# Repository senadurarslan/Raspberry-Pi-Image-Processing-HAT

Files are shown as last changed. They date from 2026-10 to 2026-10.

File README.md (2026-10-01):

# Raspberry Pi Image Processing HAT

A custom **Raspberry Pi 4 Model B HAT** designed for image capture, processing, and display using an **ArduCAM OV2640 camera**, **ST7735 TFT display**, and an **LM2596S-3.3 based switching power supply**.

<p align="center">
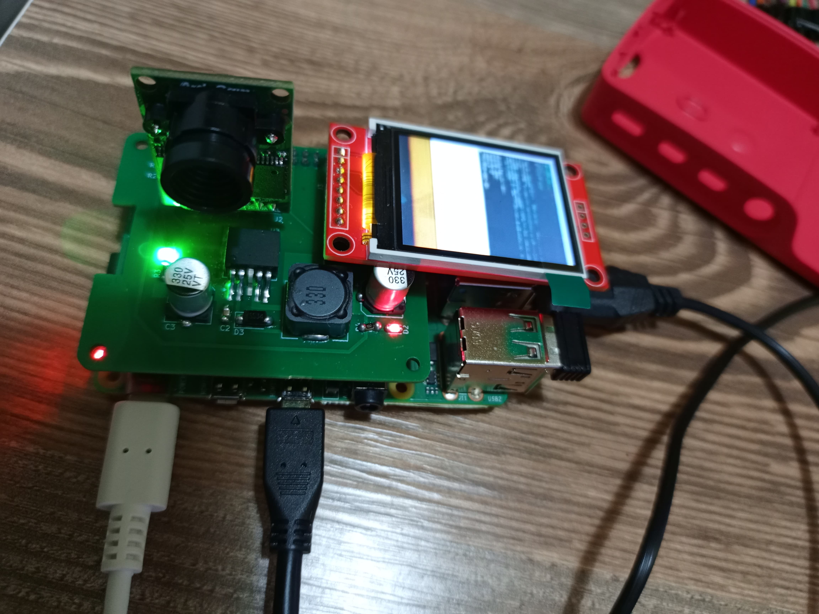
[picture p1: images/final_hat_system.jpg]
Raspberry Pi Image Processing HAT
  
</p>

## Project Overview

This project focuses on the design and implementation of a custom Hardware Attached on Top (**HAT**) board for the Raspberry Pi 4 Model B.

The system captures images using an **ArduCAM OV2640 camera**, processes the image data on the Raspberry Pi, and displays the resulting output on an **ST7735 TFT display**.

A custom PCB was designed to integrate the camera, display, Raspberry Pi GPIO interface, and power management circuitry into a compact embedded vision platform.

The main hardware blocks are:

- **Processing Unit:** Raspberry Pi 4 Model B
- **Image Capture:** ArduCAM Mini OV2640
- **Display:** ST7735 TFT
- **Power Management:** LM2596S-3.3 based SMPS
- **Custom Hardware:** Raspberry Pi HAT PCB

---

## System Architecture

The Raspberry Pi acts as the main processing and control unit.

The **ArduCAM OV2640** communicates with the Raspberry Pi using:

- **I²C** for camera sensor configuration
- **SPI** for image data transfer

The **ST7735 TFT display** uses:

- **SPI** for command and pixel data transfer
- GPIO signals for display control and reset

The overall image processing flow is:

```text
        ArduCAM OV2640
              │
       ┌──────┴──────┐
       │             │
      I²C           SPI
Configuration    Image Data
       │             │
       └──────┬──────┘
              ▼
       Raspberry Pi 4
              │
       JPEG Acquisition
              │
       Buffer Processing
              │
        JPEG Decoding
              │
       RGB565 Conversion
              │
              ▼
       ST7735 TFT Display
```

---

## Hardware Design

The custom HAT PCB was designed using **KiCad EDA**.

The hardware design includes:

- Raspberry Pi 40-pin GPIO interface
- ArduCAM OV2640 camera connector
- ST7735 TFT display connector
- LM2596S-3.3 switching regulator
- SPI communication lines
- I²C communication lines
- Dedicated chip-select signals
- Power distribution circuitry
- Ground plane for improved signal integrity
- SMD and THT components

The PCB was designed as a **two-layer board** and manufactured using the generated Gerber files.

After production, the components were assembled and the board was mounted directly onto the Raspberry Pi for functional testing.

---

## Power Management

An **LM2596S-3.3 based switching power supply (SMPS)** was integrated into the HAT design.

The power stage converts the available supply voltage to the required **3.3 V rail** for the peripheral hardware.

A switching regulator was preferred to provide:

- Higher energy efficiency
- Reduced thermal losses
- Stable output voltage
- Better performance under varying current loads
- Improved suitability for embedded applications

---

## Software Architecture

The software was developed using **C and C++** on Raspberry Pi OS.

The implementation includes:

- ArduChip communication
- OV2640 sensor initialization
- I²C communication
- SPI communication
- JPEG image acquisition
- JPEG file storage
- JPEG decoding
- RGB565 image conversion
- ST7735 TFT display control
- Camera and display integration
- Hardware test programs

### Main Source Files

```text
arduchip.c
arduchip.h

ov2640.c
ov2640.h
ov2640_regs.c
ov2640_regs.h

spi_linux.c
spi_linux.h

i2c_linux.c
i2c_linux.h

jpeg_to_rgb565.c
jpeg_to_rgb565.h

capture_to_file.c
capture_to_screen.cpp
decode_test.c

test_arduchip.c
test_hal.c
```

---

## Build System

The project includes a **Makefile** for compiling and running the camera, image processing, and TFT applications.

### Compilers

The project uses:

```text
gcc
g++
```

The full camera-to-display application is compiled using:

```text
-std=gnu++20
```

### Libraries

The TFT application uses:

```text
rpidisplaygl
lgpio
librt
```

with:

```text
/usr/local/include
/usr/local/lib
```

---

## Build & Run

### Show Available Commands

```bash
make
```

The default target displays the available build and run commands.

### Clean Build Files

```bash
make clean
```

This removes generated object files, executables, and temporary image files such as:

```text
frame.jpg
frame.rgb565
```

---

### ArduChip SPI Test

Compile:

```bash
make test_arduchip
```

Run:

```bash
make run_test_arduchip
```

This test verifies communication with the ArduChip interface.

---

### OV2640 Initialization Test

Compile:

```bash
make test_hal
```

Run:

```bash
make run_test_hal
```

This test verifies OV2640 initialization and communication through the hardware abstraction layer.

---

### Capture JPEG Image

Compile:

```bash
make capture_app
```

Run:

```bash
make run_capture_app
```

The application captures an image from the OV2640 camera and stores the acquired JPEG data.

---

### JPEG to RGB565 Conversion

Compile:

```bash
make decode_test
```

Run:

```bash
make run_decode_test
```

This application tests the conversion of captured JPEG image data into the **RGB565** pixel format used by the TFT display.

---

### Full Camera-to-TFT Pipeline

Compile:

```bash
make capture_screen
```

Run:

```bash
make run_capture_screen
```

This application combines the complete image pipeline:

```text
Camera
  ↓
JPEG Capture
  ↓
Image Processing
  ↓
RGB565 Conversion
  ↓
ST7735 TFT
```

---

# Project Gallery

## Final Integrated HAT System

The final implementation combines the custom HAT PCB, **ArduCAM OV2640 camera**, **ST7735 TFT display**, onboard power stage, and Raspberry Pi into a single integrated system.

<p align="center">
  Final Raspberry Pi HAT System
</p>

---

## Camera Capture Test

The OV2640 camera was configured and tested on the Raspberry Pi.

Image data captured from the camera was transferred to the Raspberry Pi and successfully stored as a JPEG image.

<p align="center">
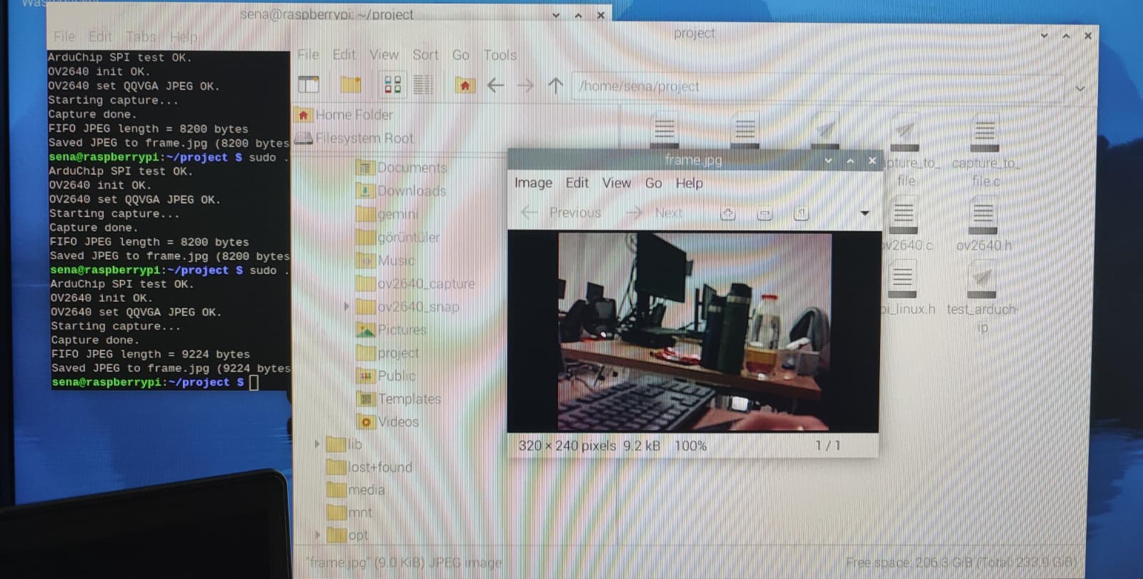
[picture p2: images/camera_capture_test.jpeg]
OV2640 Camera Capture Test
  
</p>

The terminal output verifies the camera communication and image acquisition process, including:

```text
ArduChip SPI test OK
OV2640 init OK
Starting capture...
Capture done
Saved JPEG to frame.jpg
```

---

## Camera-to-TFT Integration Test

The image captured by the OV2640 camera was processed by the Raspberry Pi and displayed on the ST7735 TFT.

<p align="center">
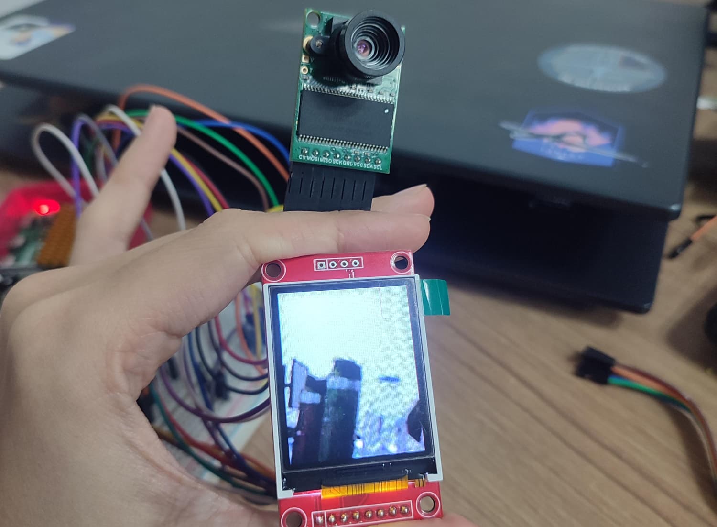
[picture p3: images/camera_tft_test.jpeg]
Camera to TFT Integration Test
  
</p>

This test demonstrates the complete image pipeline from **camera acquisition to TFT visualization**.

---

## Testing

The system was tested incrementally before full integration.

The main test stages included:

- ArduChip SPI communication test
- OV2640 initialization test
- I²C sensor configuration
- SPI image data transfer
- JPEG image capture
- JPEG file storage
- JPEG decoding
- RGB565 conversion
- ST7735 graphical tests
- PCB electrical tests
- Camera and display integration
- Full system functional test

The final system successfully captured image data from the OV2640 camera, processed the image on the Raspberry Pi, and displayed the resulting image on the ST7735 TFT.

---

## PCB Development

The PCB development process consisted of:

```text
System Requirements
        ↓
Component Selection
        ↓
Schematic Design
        ↓
PCB Layout
        ↓
Gerber Generation
        ↓
PCB Manufacturing
        ↓
Component Assembly
        ↓
Electrical Testing
        ↓
Raspberry Pi Integration
        ↓
Functional Testing
```

The PCB design files and manufacturing outputs are included in the repository.

---

## Technologies & Tools

### Hardware

- Raspberry Pi 4 Model B
- ArduCAM OV2640
- ST7735 TFT
- LM2596S-3.3
- Custom Raspberry Pi HAT PCB

### Communication

- SPI
- I²C
- GPIO

### Software

- C
- C++
- GNU Make
- Raspberry Pi OS

### PCB Design

- KiCad EDA
- Gerber
- Two-layer PCB design

---

## Repository Contents

The repository contains:

```text
Raspberry-Pi-Image-Processing-HAT/
│
├── images/
│   ├── final_hat_system.jpg
│   ├── camera_capture_test.jpeg
│   └── camera_tft_test.jpeg
│
├── KiCad/
│   └── PCB and schematic design files
│
├── mühtas_1_project/
│   ├── Camera drivers
│   ├── SPI / I²C drivers
│   ├── Image processing files
│   ├── TFT application
│   └── Makefile
│
├── rapor/
│   └── Project documentation and reports
│
└── README.md
```

---

## Documentation

Detailed project documentation, design reports, system requirements, and test procedures are available in the repository.

The project documentation covers:

- System architecture
- Hardware design
- Power management
- Camera communication
- TFT communication
- PCB design
- Manufacturing
- Software development
- Integration
- Functional testing

---

## Project Context

This project was developed as part of the **MÜHTAS-1 Engineering Design Project** in the **Department of Electronics and Communication Engineering at Kocaeli University**.

The project combines embedded software development, digital communication interfaces, PCB design, power electronics, and image processing into a complete embedded vision system.

---

## Author

**Sena Sümeyye Durarslan**

Electronics and Communication Engineering  
Kocaeli University

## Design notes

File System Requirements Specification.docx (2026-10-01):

System Requirements Specification

AMAÇ: Raspberry Pi’nin 40 pinlik headerı üstüne takılıp çıkarılacak bir HAT tasarlamak.

Sistem, bir kamera modülünden alınan görüntünün Raspberry Pi üzerinden işlenip ekrana aktarılmasını sağlar. Ayrıca ilerleyen aşamalarda FPGA üzerinde de kullanılabilir şekilde tasarlanmayı amaçlar.

Donanım Gereksinimleri:

- VGA çözünürlüklü bir kamera modülü(OV7670 / OV2640)
- Raspberry Pi 4 (işleme+kontrol)
- TFT ekran (ST7735)

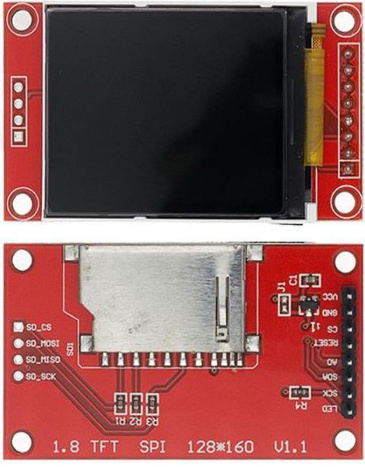
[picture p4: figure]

Yazılım Gereksinimleri:

- Kamera görüntüsünü yakalamak
- Görüntüyü çözünürlük küçültme/ölçekeleme yaparak işleme
- Ekranda gösterme

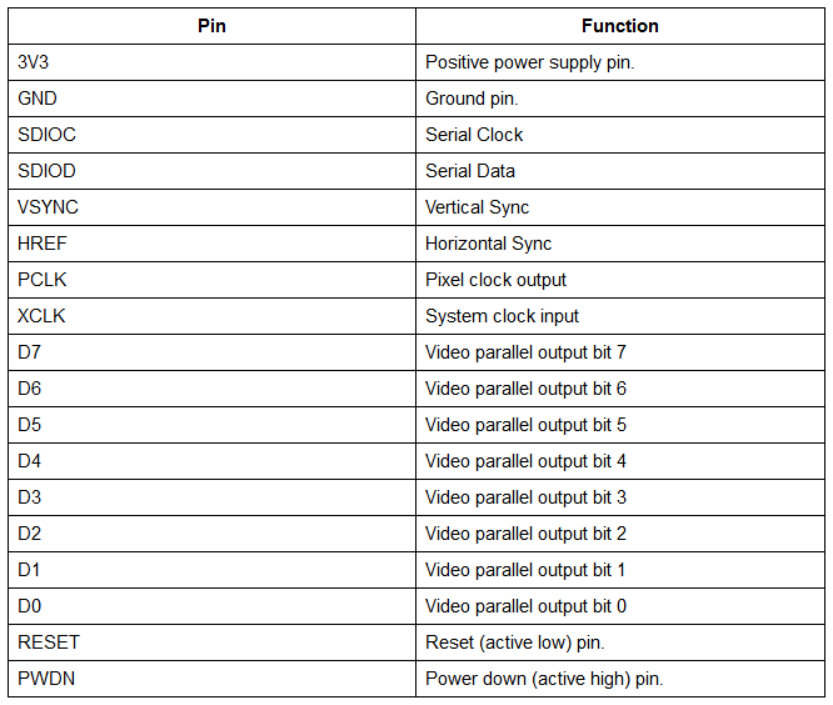
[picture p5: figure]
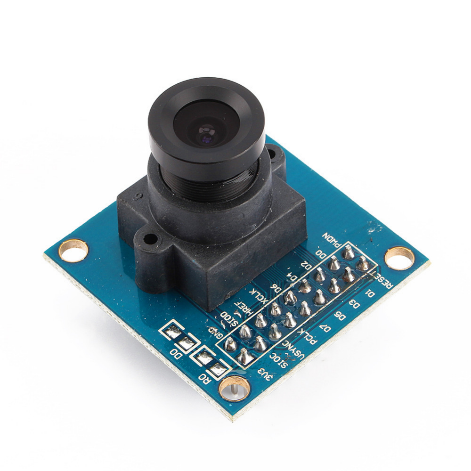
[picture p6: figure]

PROJE ARAŞTIRMASI YAPILIRKEN BELİRLENEN GEREKSİNİMLER VE NEDENLERİ:

Raspberry Pi kartlarında kamera kullanımı için özelleştirilmiş CSI portu bulunmaktadır ancak proje kapsamında tasarladığımız kart üzerinde bulunan GPIO pinleri üzerinden görüntü aktarımı sağlamak istediğimiz için bu portu kullanamıyoruz. Yapılan araştırılmalar sonucunda Rasoberry Pi ile CSI olmayan kameraların kullanıldığı durumlara örnek bulunamamıştır. Bunun sebeplerinden bazıları:

1. CSI bağlantısı, kameradan doğrudan Raspberry Pi’nin GPU’suna yüksek hızlı veri aktarımı sağlar. USB veya GPIO üzerinden bağlanan kameralar ise bu hızı sunamaz. Kamera modülleri saniyede milyonlarca piksel verisi (24MHZ) üretir. GPIO pinleri ise bu kadar yüksek hızda paralel veri aktarımı için tasarlanmamıştır. Sonuç: Gecikme, bozulmuş görüntü veya veri kaybı yaşanabilir.
2. CSI hattı kullanıldığında veri doğrudan GPU tarafından alınır. GPIO üzerinden veri okuma denemelerinde ise CPU sürekli pinleri okur ("polling" veya "interrupt" yöntemiyle).Bu, CPU’nun büyük kısmını meşgul eder ve diğer işlemler yavaşlar ve video işleme, akış (streaming) gibi uygulamalarda sistem kitlenebilir.
3. Linux çekirdeği (Raspberry Pi OS dahil) GPIO üzerinden kamera veri alımı için hazır sürücü içermez.Bu sebeple kendi driverımızı yazmamız gerekir.

Yapılan incelemeler sonucu VGA kameralarıın parallel portlar üzerinden görüntüyü aktardığı görülmüştür fakat Raspberry Pi’nin GPIO pinlerinin mevcut örnekleme frekansı kernel yapısı doğrultusunda 1MHZ ‘a kadar çıkabildiği daha yüksek frekanslara çıkabilmesi için Kernel yapsısının manipüle edilmesi gerektiği saptanmıştır. Bu doğrıltuda gelen görüntüyü arada bufferlayarak pararlel porttan alarak Spı portuna dönüştüren MCU devresi konulması öngörülmüştür. SPI çıkışına sahip kameraların yüksek maaliyetli olduğu belirlenmiş ve bunun yerine maaliyet olarak daha etkin olan mcu eklenmiş devrenin kullanılması öngörülmüştür.

Rapberry Pi’nin forum sitesinde (https://forums.raspberrypi.com/viewtopic.php?t=73190 ) bu konu hakkında tartışmalar yapıldığı ve farklı öneriler olduğu belirlenmiş ve araştırma yapılmıştır.

Araştırma sonucu bulunan yöntemler:

- Arducam 2MP OV2640 Mini Kamera Modülü kullanarak doğrudan SPI üzerinden haberleşme sağlanabilir. OV2640/OV7670 gibi kameralar 8 bitlik paralel veri gönderdiği ve R-Pi seri veri işlediği için problem yaşanabilmektedir. Bu modül kullanıcıya alternatif bir seçenek sunuyor. Kendi sitesinde ‘Arduino, Raspberry Pi, STM32, BeagleBone Black gibi SPIve I2C arayüzüne sahip tüm platformlarla uyumludur.’ ibaresi yer alıyor.

https://www.uctronics.com/download/Amazon/ArduCAM_Mini_2MP_Camera_Shield_DS.pdf

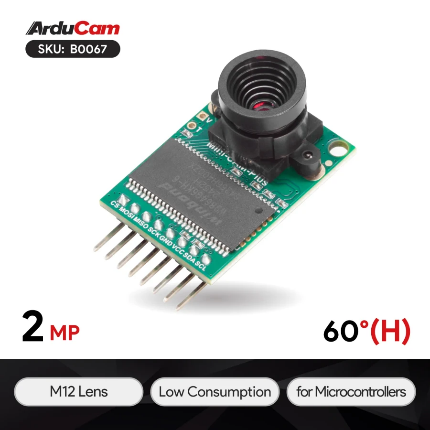
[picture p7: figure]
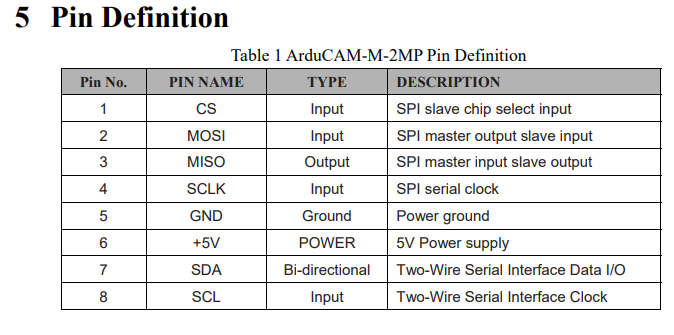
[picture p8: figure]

- OV7670 + MCU (stm32/esp32/arduino) Kamera sensörleri paralel veri üretiyor ama4

R-Pi’nin GPIO pinleri paralel veriyi o hızda doğrudan işleyemiyor ve donanımında DCMI birimi yok bu sebeple araya MCU’yu araya ekleyerek kameradan gelen veriyi Pi’nin anlayacağı yavaş, seri bir protokole çevirmeyi hedefleyebiliriz. Böylece R-Pi sadece yüksek seviye işlemi (görüntü gösterme, kaydetme, işleme) yapar; düşük seviye kamera iletişimi MCU tarafından yönetilir. Yani bu yolda MCU köprü görevi görüyor ancak burda da drive sorunu oluyor kendimizin driver yazması gerekecek

Bu yöntem seçilirse stm için Kristal, direnç,kapasitör gibi system gereçleri eklemek gerekecektir. MCU’ya kod atmak için gerekli pinlere header konularak gerekli bağlantılar yapılacak olmalıdır ve yapılabilirliği araştırılıp MCU kartı tasarlanarak tak çıkar şeklinde de yapılabilir. Kamera ve R-Pi haberleşmesi için ilgili bacaklardan gerekli pinlere yollar pcb üzerinde çizilecektir. Ama ileride FBGA kullanma durumu için kameradan görüntünün MCU’ya gitmediği ek bir yol çizilebilir yönlendirmeyi kendimizin seçebileceği.

Bu seçeneğin yapılabilirliğini elimde bulunan STM32F407 board ile deneyebiliriim.

Raspberyy Pico ile yapılan örneklerde bulunmaktadır.

Kamera → MCU → Pi (görüntü verisi) → ST7735 ekran

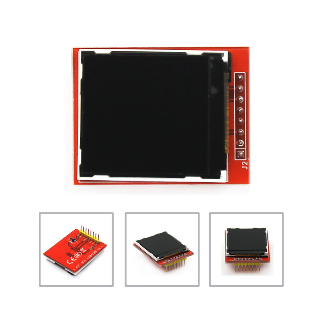
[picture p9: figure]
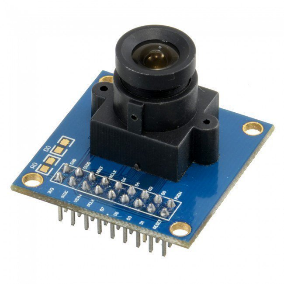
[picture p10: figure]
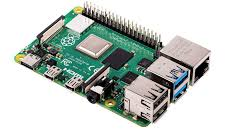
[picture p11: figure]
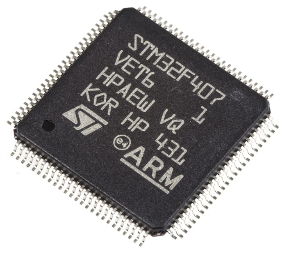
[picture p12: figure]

- Raspberry Pi DMA+GPIO kamera-gpıo(dma)-frame buffer-opencv-ekran şeklinde nir yöntem kullanılabilir. Bu durumda ek bir donanıma gerek kalmaz tamamen Pi üzerinden HAT tasarımını kontrol edebilirim. Bu yönyemin de kendi içinde avantaj ve dezevantajları bulunuyor: GPIO hız sınırlaması nedeniyle FPS düşük olabilirr ve DMA ayarları gerekir.

Frame buffer = pixel pixel veriyi alıp kaç tane pixel varsa TFT ekranda aynı şekilde basıyorsun. Toplam pixelimi arrayda tutuyorum (1000 pixel geliyorsa 1000’lik arrayda tuttum) daha sonra ekrana basıyorum. Ekran 2000 pixellik bir ekranda 2 pixele 1 tane pixeli basıyoruz gibi bir algoritma düzenleyebiliriz

- USB Kamera kullanılabilir ancak maliyet açısından yüksek bütçeli bir yöntem

Bu durumlar karşılaştırıldığında hepsinin avantaj ve dezavantajları bulunmaktadır. DMA seçeneğinde 1Mhz örnek alma seçeneği olduğu ve daha fazla örnekleme alınması istendiğinde Kernelın kodlarına inerek müdahale edilmesi gerektiği saptandığı için bu durum daha fazla yazılım maaliyeti ve ek iş süresi demektir. R-Pi(pico harici) ile yapılan örnek projeleri bulamadığım GPIO üzerinden veri alınmak istendiğinde kameraya ait driver sürücülerini R-Pi ye port etmek gerekiyor diye düşünmekteyim. Ana amacımız donanım tasarlamak olduğu için bu seçenek taslak olarak sunulmuş ve MCU devresi tasarlanacak şekilde bir taslak şema oluşturulmuştur.

Proje kapsamında donanıma dikkat edileceği için ona göre tasarım örneği sunulmuştur.

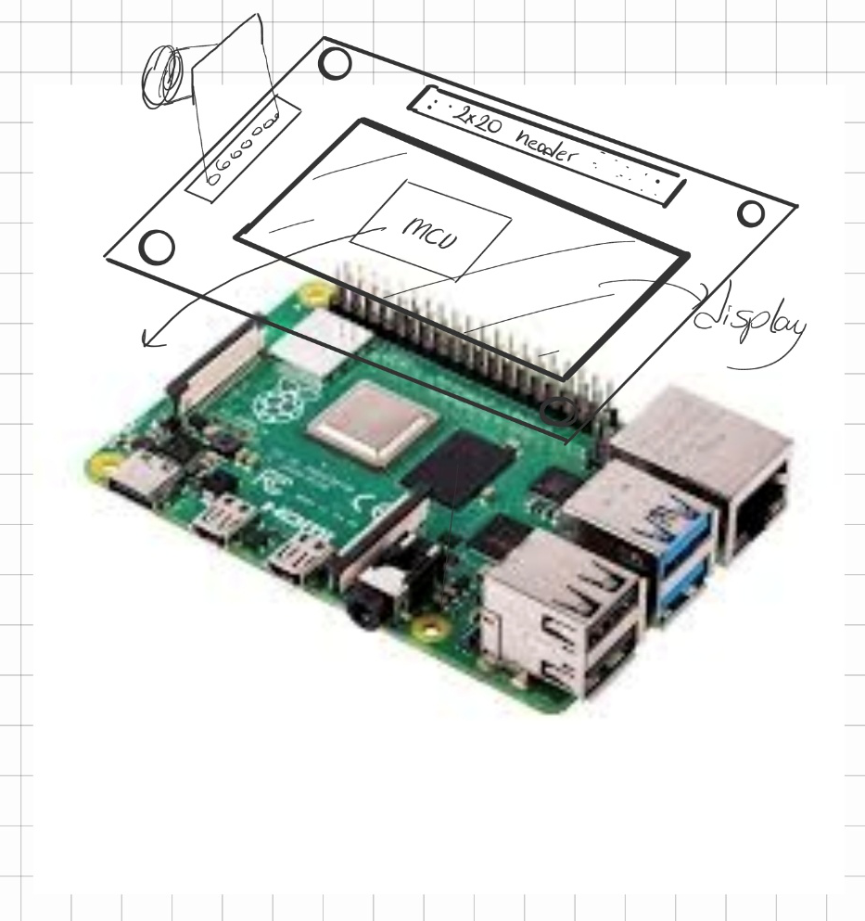
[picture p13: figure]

TASLAK TASARIM:

Bu doğrultuda devre için gerekli olan alt componentlere girmeden ana componentler belirlenmiştir. Devre modeli toplantıda belirlendikten sonra devre için gerekli olan componentler çıkartılacaktır ve buna bağlı olarak maaliyet hesabı yapılacaktır.

İlgili üretim devre tasarımı yapıldıktan sonra ,,,,,,,,,,,,,,,,,,,, üretime gönderilecektir

Test aşaması:

1. Elimde STMF407 kart bulunduğu için kamera ve TFT ekran sipariş edilecek daha sonra kameradan alınan görüntü ekranda stm üzerinden oluşturulacak ve bu test ile kamera ile Stm arasına kodun doğruluğu test edilmiş olacağı planlanmaktadır.
2. Bu doğrulama sonrası STM’den gelen görüntü verilerini R-Pi üzerinden ekranda gözlemlenmek isteniyor.

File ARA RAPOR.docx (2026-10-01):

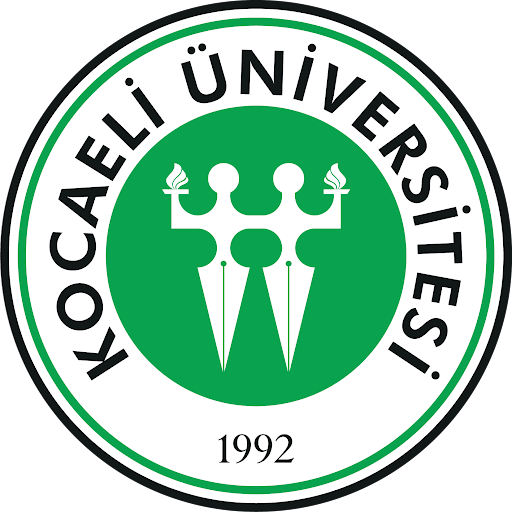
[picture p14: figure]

KOCAELİ ÜNİVERSİTESİ

MÜHENDİSLİK FAKÜLTESİ

ELEKTRONİK VE HABERLEŞME MÜHENDİSLİĞİ

GÖRÜNTÜ İŞLEME HAT PROJESİ ARA RAPORU

HAZIRLAYAN

ÖĞRENCİNİN ADI VE SOYADI: SENA SÜMEYYE DURARSLAN

ÖĞRENCİNİN NUMARASI: 220208041

PROJE DERSİ: MÜHENDİSLK TASARIM - 1

İÇİNDEKİLER:

1. PROJENİN AMACI
2. BLOK ŞEMASI
3. ŞEMATİK
4. PCB / 3D GÖRÜNTÜ
5. MALZEME LİSTESİ
1. GIRIŞ

Bu proje kapsamında, Raspberry Pi headerları aracılığıyla çalışabilecek, ArduCAM Mini OV2640 görüntü sensörü ile ST7735 TFT ekranın aynı donanım üzerinde entegre biçimde çalışmasını mümkün kılan bir HAT (Hardware Attached on Top) kartı tasarlanmıştır. Tasarlanan kart, kamera aracılığıyla alınan görüntülerin Raspberry Pi üzerinde işlenmesi ve TFT ekranda görüntülenmesi amacıyla geliştirilmiştir. Bu doğrultuda, hem kamera hem ekran için gerekli SPI ve I²C arayüzleri kart üzerinde yönetilmiş, ayrıca sistemin güç gereksinimleri için bir DC–DC dönüştürücü devresi entegre edilmiştir.

2. SİSTEM BİLEŞENLERİNİN TEKNİK ANALİZİ

Sistem, işlevselliğini yerine getirmek için üç temel donanım bileşenine dayanmaktadır: Görüntü sensörü, görüntü denetleyicisi ve anahtarlamalı güç kaynağı (SMPS).

i. Arducam OV2640 Kamera Modülü

Görüntü yakalama işlevi, 2 megapiksel çözünürlüğe sahip bir CMOS sensör olan OV2640'ı içeren Arducam modülü ile sağlanmaktadır. Modül, karmaşık sensör kontrolünü basitleştiren ve veri transferini kolaylaştıran özel bir ArduChip kontrolcüsüne sahiptir.

Parametre | Değer | İşlevsel Açıklama
Sensör Çözünürlüğü | 2 MP (1600x1200) | Maksimum görüntü yakalama kapasitesi.
Veri Arayüzü | SPI | Yüksek hızlı görüntü verisi aktarımı için kullanılır. Maksimum 8 MHz saat hızı desteklenir.
Kontrol Arayüzü | I²C | Sensör kayıtlarının konfigürasyonu (çözünürlük, sıkıştırma, pozlama) için kullanılır. Adres: 0x60 (Yazma) / 0x61 (Okuma)
Güç Gereksinimi | 5 V | Modülün besleme gerilimi.
Sıkıştırma | Dahili JPEG | Veri hacmini azaltarak Raspberry Pi'ye aktarım hızını optimize eder. Hedef çözünürlük QVGA (640x480) olarak belirlenmiştir

ii. ST7735 TFT Ekran Modülü

Görüntüleme birimi, ST7735 denetleyicisine sahip bir TFT modülüdür. Bu denetleyici, 262K renk derinliğini desteklemekte ve yüksek hızlı seri arayüzler aracılığıyla veri kabul edebilmektedir.

Parametre | Değer | İşlevsel Açıklama
Denetleyici | | 132x162 piksel çözünürlüğe kadar destekler.
Arayüz | | Yüksek hızlı piksel verisi transferi için kullanılır. SPI0.1 hattına bağlanmıştır
Güç Gereksinimi | | Ekranın mantık ve besleme voltajı 3.3V'tur.
Renk Formatı | | Görüntü işleme yazılımının hedeflediği piksel formatıdır. 40.960 byte veri aktarımı gereklidir

iii. GÜÇ YÖNETİMİ VE SMPS TERCİHİ
- Voltaj Regülatörünün Entegrasyonu

Raspberry Pi'nin 5V hattından alınan gücü, 3.3V ile çalışan bileşenler için stabil ve yeterli akım kapasitesine sahip bir kaynağa dönüştürmek amacıyla harici bir voltaj regülatörü eklenmiştir. Bu, Raspberry Pi'nin dahili 3.3V regülatörünün potansiyel aşırı yüklenmesini önler ve sistemin güvenilirliğini artırır.

- Anahtarlamalı Güç Kaynağı (SMPS) Seçimi ve Devre Detayları

Projede, lineer regülatörler yerine LM2596S-3.3 entegresine dayalı bir Anahtarlamalı Güç Kaynağı (SMPS) devresi tercih edilmiştir. Bu tercih, entegrenin yüksek verimlilik (tipik %70 - %90) ve yüksek çıkış akımı (3 A'e kadar) kapasitesi sayesinde termal yönetimi kolaylaştırması ve enerji kaybını minimize etmesi nedeniyledir

LM2596S-3.3, 150 kHz sabit frekansta çalışan bir Buck dönüştürücüdür.

3. SISTEM MIMARISI VE BLOK ŞEMASI

Sistem mimarisi genel hatlarıyla dört ana bloktan oluşmaktadır:

1. Raspberry Pi HAT Arayüzü (2×20 pin header)
2. ArduCAM Mini 2 MP kamera modülü
3. ST7735 tabanlı SPI TFT ekran modülü
4. LM2596S-3.3 tabanlı anahtarlamalı güç dönüştürücü (SMPS)

Şekil 1’de sistemin blok diyagramı gösterilmektedir. Blok diyagramında Raspberry Pi, SPI ve I²C hatları üzerinden kamera ve ekrana bağlanmakta; 5 V güç hattı ise kart üzerindeki LM2596S-3.3 düşürücü dönüştürücü aracılığıyla kararlı 3,3 V seviyesine dönüştürülmekte ve besleme olarak kullanılmaktadır.

4. Donanım Bileşenleri

A. Raspberry Pi HAT Bağlantı Konnektörü

Kart, Raspberry Pi’nin 40 pinlik GPIO başlığına uyumlu olacak şekilde 2×20 pinlik header içermektedir. Bu konnektör üzerinden:

- SPI0 (MOSI, MISO, SCLK, CE0/CE1),
- I²C (SDA, SCL),
- 5 V ve 3,3 V besleme hatları,
- GND referansı doğrudan HAT kartına aktarılmaktadır.

B. ArduCAM Mini OV2640 Kamera Modülü

Kamera birimi olarak ArduCAM Mini 2 MP SPI kamera kalkanı kullanılmaktadır. Bu modül, Omnivision firmasına ait OV2640 CMOS görüntü sensörü ile ArduCAM’in kendi ArduChip denetleyicisini tek kart üzerinde birleştirmektedir.

Modül;

- 2 MP (1600×1200) etkin çözünürlük,
- 5 V tipik 70 mA besleme akımı,
- JPEG, RAW, YUV ve RGB format desteği,
- 384 kB dahili FIFO kare tamponu,
- SPI tabanlı veri aktarımı ve I²C tabanlı sensör konfigürasyonu

gibi özelliklere sahiptir.

Kamera pini | Açıklama | HAT etiketi | Raspberry Pi GPIO
CS | SPI chip select | CS_CAM | GPIO8 (CE0)
MOSI | SPI veri girişi | MOSI | GPIO10
MISO | SPI veri çıkışı | MISO | GPIO9
SCLK | SPI saat | SCK_CAM | GPIO11
+5V | Besleme | 5V | 5 V hattı
GND | Toprak | GND | GND
SDA | I²C veri | SDA_CAM | GPIO2 (SDA1)
SCL | I²C saat | SCL_CAM | GPIO3 (SCL1)

Kamera sensörünün tüm yapılandırma kayıtları (çözünürlük, pozlama, beyaz dengesi vb.) I²C üzerinden yapılandırılabilmekte, görüntü verisi ise SPI üzerinden okunmaktadır.

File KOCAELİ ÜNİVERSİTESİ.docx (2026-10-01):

KOCAELİ ÜNİVERSİTESİ

MÜHENDİSLİK FAKÜLTESİ

RASPBERRY Pİ HAT

....... . DÖNEM PROJESİ

Öğrencinin Adı Soyadı:

SENA SÜMEYYE DURARSLAN

Bölümü: Elektronik ve Haberleşme Mühendisliği

Danışman: Yrd. Doç. Dr. ANIL ÇELEBİ

KOCAELİ, 2025

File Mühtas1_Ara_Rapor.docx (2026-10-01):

KOCAELİ ÜNİVERSİTESİ

MÜHENDİSLİK FAKÜLTESİ

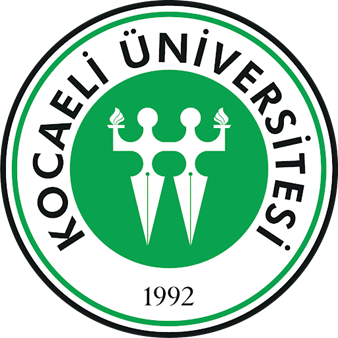
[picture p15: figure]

RASPBERRY Pİ GÖRÜNTÜ İŞLEME HAT PROJESİ

MÜHTAS-1

2025-2026 1. DÖNEM PROJESİ

Öğrencinin Adı Soyadı:

Sena Sümeyye DURARSLAN

Bölümü: Elektronik ve Haberleşme Mühendisliği

Danışman: Yrd. Doç. Dr. Anıl ÇELEBİ

KOCAELİ, 2025

# İÇİNDEKİLER

1. İçindekiler ii

2. Güç Yönetiminde SMPS Kullanımının Gerekçesi……………………………… 3

3. Projede Yapılan Çalışmalar 4

3.1 Kavramsal Tasarım 4

3.2 Projede Gerçekçeşen İş Paketleri ve Ara Çıktıları 6

3.3 Kamera ve Ekran Deneme Testleri ……………………………………………… 8

3.4 Şematik Ve Pcb Tasarımı ………………………………………………………. 10

4. Kaynaklar …………………………………………………………………………14

# 1. GİRİŞ

Bu proje, Raspberry Pi 4 Model B platformu için özel olarak tasarlanmış bir HAT (Hardware Attached on Top) kartı geliştirmeyi amaçlamaktadır. Projenin temel gereksinimi, Arducam OV2640 kamera modülünden elde edilen görüntü verisini Raspberry Pi üzerinde işlemek ve elde edilen çıktıyı ST7735 TFT ekran modülü aracılığıyla görselleştirmektir.

Proje, gömülü sistemler alanında düşük maliyetli, enerji verimli ve kompakt bir görüntü işleme ve görüntüleme çözümü sunarak, özellikle robotik, uzaktan izleme ve taşınabilir görüntüleme sistemleri gibi uygulama alanlarındaki sorunları çözmeyi hedeflemektedir.

Sistemin genel yapısı, üç ana modülün Raspberry Pi'ye entegrasyonu üzerine kuruludur:

1. Görüntü Yakalama Modülü: Arducam Mini-M- OV2640
2. Görüntüleme Modülü: ST7735 TFT Ekran
3. Güç Yönetim Modülü: LM2596S-3.3 tabanlı SMPS devresi.

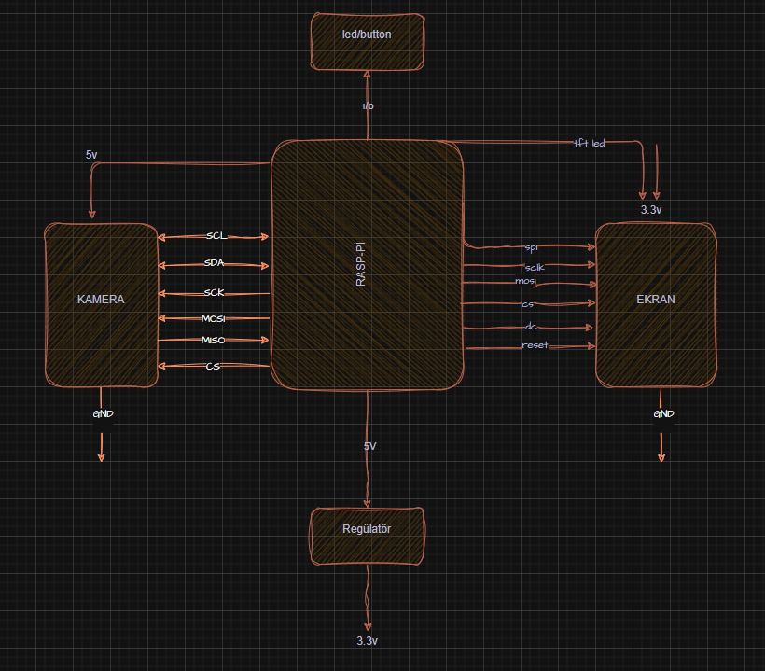
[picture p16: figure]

Şekil 1.1

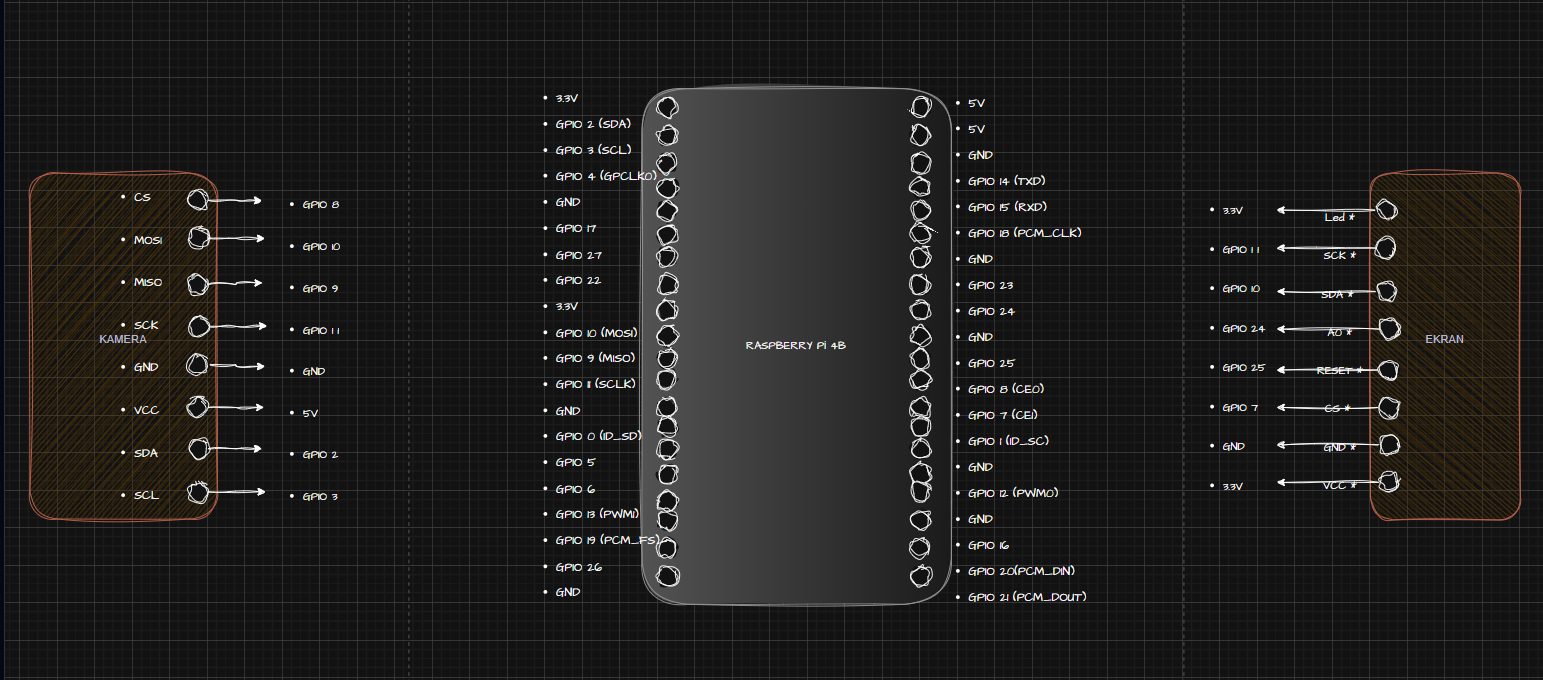
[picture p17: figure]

Şekil 1.2

Projenin genel mimarisi, Şekil 1.1'de gösterilen blok diyagramı ile özetlenmektedir. Merkezi işlem birimi olan Raspberry Pi, sistemin ana kontrolcüsü olarak görev yapmaktadır.

Görüntü yakalama birimi olan Kamera (Arducam OV2640) ile Raspberry Pi arasındaki iletişim, hem yüksek hızlı veri transferi için SPI (SCK, MOSI, MISO, CS) hem de sensör konfigürasyonu için I²C (SDA, SCL) protokolleri üzerinden sağlanmaktadır.

Görüntüleme birimi olan Ekran (ST7735) ise Raspberry Pi'den gelen işlenmiş veriyi SPI (SCK, MOSI, CS, DC, RESET) üzerinden almaktadır. Sistemin enerji verimliliğini ve kararlılığını sağlamak amacıyla, Raspberry Pi'nin 5V hattından beslenen harici bir Regülatör (LM2596S-3.3), Kamera ve Ekran modüllerinin gerektirdiği 3.3V ve 5V besleme gerilimlerini sağlamaktadır.

Donanım entegrasyonunun temelini oluşturan pin atamaları, Şekil 1.2'de gösterilmiştir. Görüntü verisinin hızlı aktarımı için kritik olan SPI arayüzü, Raspberry Pi'nin donanımsal SPI0 hattına tahsis edilmiştir: GPIO 11 (SCK) ve GPIO 10 (MOSI) kamera ve ekran için ortak hatlar olarak kullanılmaktadır. Her iki modülün bağımsız kontrolü için GPIO 8 (CS) Kameranın Chip Select sinyaline, GPIO 7 (CS) ise Ekranın Chip Select sinyaline atanmıştır. Kamera sensörünün konfigürasyonu için I²C protokolü, Raspberry Pi'nin standart I²C1 hattı olan GPIO 2 (SDA) ve GPIO 3 (SCL) pinleri üzerinden sağlanmıştır. Ekranın komut/veri ayrımı için GPIO 25 (DC) ve donanımsal sıfırlama için GPIO 24 (RESET) pinleri kullanılarak mantıksal kontrol sağlanmıştır

2. Güç Yönetiminde SMPS Kullanımının Gerekçesi

Sistemin güç gereksinimlerini karşılamak amacıyla LM2596S-3.3 entegresi tabanlı anahtarlamalı güç kaynağı (SMPS) tercih edilmiştir. Raspberry Pi’nin 5 V besleme hattından kamera ve TFT ekran modülünün gerektirdiği 3.3 V gerilimin elde edilmesi sürecinde yüksek enerji verimliliği, düşük ısı kaybı ve kararlı çıkış gerilimi sağlanması hedeflenmiştir.

Lineer regülatör tabanlı çözümlerde, giriş ve çıkış gerilimleri arasındaki fark ısıya dönüşür. Özellikle akım tüketimi yüksek veya zamana bağlı olarak değişken olan sistemlerde ciddi güç kayıpları ve termal sorunlar ortaya çıkabilmektedir. Bu durum, hem sistemin enerji verimliliğini düşürmekte hem de uzun süreli çalışmalarda güvenilirliği olumsuz etkilemektedir.

Anahtarlamalı güç kaynakları ise enerjiyi anahtarlama elemanları aracılığıyla yüksek verimle dönüştürdüğünden, aynı güç seviyesinde lineer regülatörlere kıyasla çok daha düşük ısı kaybı oluşturmaktadır. Bu sayede, kamera ve ekran gibi ani ve değişken akım çekişine sahip modüllerin beslendiği uygulamalarda çıkış geriliminin daha kararlı tutulması mümkün olmaktadır.

Sonuç olarak, SMPS kullanımı; sistemin termal kararlılığını artırmakta, enerji verimliliğini yükseltmekte ve gömülü sistemler için kritik öneme sahip olan uzun süreli, güvenilir ve taşınabilir çalışma gereksinimlerini karşılayan bir güç yönetimi çözümü sunmaktadır.

# 3. PROJEDE YAPILAN ÇALIŞMALAR

## 3.1 Kavramsal Tasarım

Temel Aşamalar:

Sistem Analizi ve Gereksinim Belirleme

- Proje hedeflerinin tanımlanması
- Donanım/yazılım gereksinimlerinin belirlenmesi

Sistem Mimarisi Tasarımı

- Blok diyagramların oluşturulması
- Modüller arası iletişim protokollerinin belirlenmesi (SPI, I2C, GPIO vb.)
- Veri akış şemalarının tasarlanması

Donanım Tasarımı

- Komponent seçimi ve tedarik
- Devre şematiği tasarımı
- PCB tasarımı
- Breadboard/prototip kurulumu

Yazılım Geliştirme

- Test yazılımları
- Driver geliştirme (örn: kamera sürücüleri)
- Ana uygulama yazılımı

Entegrasyon ve Test

- Modül testleri
- Sistem entegrasyonu
- Performans testleri
- Hata ayıklama ve optimizasyon

Proje, donanım tasarımı, PCB üretimi ve yazılım geliştirme olmak üzere üç ana aşamada yapılandırılmıştır.

A. Donanım Tasarım Aşaması
1. Bileşen Seçimi ve Analizi: Projenin temel işlevlerini yerine getirecek Arducam OV2640, ST7735 ve LM2596S-3.3 gibi kritik bileşenlerin teknik veri sayfaları incelenmiş ve arayüz uyumlulukları (SPI, I²C) ile devre bileşen gereklilikleri doğrulanmıştır.
2. Şematik Tasarım: KiCad EDA yazılımı kullanılarak Raspberry Pi'nin 40-pin GPIO headerına uygun pin atamaları (SPI hatlarının paylaşımı, I²C pull-up dirençleri) ve LM2596S-3.3 entegresinin çevresel bileşenlerini (bobin, diyot, kapasitörler) içeren devre şeması oluşturulmuştur.
3. PCB Yerleşim Tasarımı: HAT form faktörüne uygun olarak, yüksek hızlı sinyal bütünlüğünü, güç yönetimini, ekran ve kamera konumlarını gözeten bir PCB yerleşimi tasarlanmıştır. Bu aşamada, güç hatları için geniş izler ve gnd için via'lar kullanılarak tasarım optimizasyonu yapılmıştır.

B. PCB Üretim ve Montaj Aşaması

1. PCB Üretimi: Tasarlanan Gerber dosyaları kullanılarak HAT kartının fiziksel üretimi JLCPCB firmasından sipariş edilerek gerçekleştirilmiştir..
2. Bileşen Montajı: SMD bileşenleri (LM2596S-3.3, dirençler, kapasitörler, bobin, diyot) ve header'lar PCB üzerine lehimlenerek HAT tasarım kartı oluşturulmuştur.

C. Yazılım Geliştirme ve Entegrasyon Aşaması

1. Sürücü Geliştirme: Raspberry Pi OS üzerinde C/C++ programlama dili kullanılarak, Arducam OV2640 için I²C üzerinden konfigürasyon ve SPI üzerinden veri okuma sürücüleri geliştirilecektir. Aynı zamanda ST7735 ekran için SPI üzerinden komut ve piksel verisi gönderme işlevleri programlanacaktır.
2. Görüntü İşleme Algoritması: Kameradan alınan JPEG formatındaki veriyi çözmek ve ST7735 ekranın gerektirdiği RGB565 formatına dönüştürmek için bir görüntü işleme algoritması uygulanacaktır.
3. Sistem Entegrasyonu ve Test: Geliştirilen donanım ve yazılım birleştirilerek, sistemin görüntü yakalama, işleme ve görüntüleme işlevlerini beklenen performans ve stabilite ile yerine getirip getirmediği adım adım test kodlarıyla Makefile dosyası üzerinden kontrol edilecektir.

## 3.2 Projede Gerçekçeşen İş Paketleri ve Ara Çıktıları

Projenin final rapor dönemine kadar olan sürecinde, donanım tasarımı ve yazılım geliştirme aşamaları tamamlanmış; sistemin temel mimarisi, donanım-yazılım entegrasyonu ve fonksiyonel testleri başarıyla gerçekleştirilmiştir. Bu bölümde, proje kapsamında yürütülen iş paketleri ve elde edilen somut çıktılar sunulmaktadır.

## a. Literatür Taraması ve Proje Hazırlığı

Proje başlangıcında, benzer görüntü işleme uygulamaları üzerine bir literatür taraması yapılmıştır. Ayrıca, projenin etkin yönetimi için GitLab (versiyon kontrolü-kod depolama-proje görseleri-Kicad dosyaları vb.) ve Trello (görev takibi-iş akışı yönetimi-toplantı notları vb.) gibi proje yönetim araçlarının kullanımı araştırılmıi ve kullanılmıştır. Görev takibi yoğunluklu olarak Trello üzerinden yapılmıştır.

## b. Ayrık Modül Testleri

## Sistem entegrasyonuna geçilmeden önce, kritik donanım modüllerinin Raspberry Pi platformu ile ayrı ayrı testi gerçekleştirilmiştir. Bu yaklaşım, entegrasyon aşamasında oluşabilecek hataların erken tespit edilmesini sağlamıştır.

## 1. ST7735 TFT Ekran Testleri: ST7735 ekran modülüne SPI arayüzü üzerinden test desenleri ve grafik verileri gönderilerek ekran sürücüsünün doğru çalıştığı doğrulanmıştır.

2. ArduCAM OV2640 Kamera Testleri:
OV2640 kamera modülünün I²C arayüzü üzerinden sensör konfigürasyonu ve SPI arayüzü üzerinden görüntü verisi aktarımı test edilmiştir. Kamera tarafından üretilen JPEG formatındaki görüntü verilerinin Raspberry Pi’ye hatasız şekilde aktarılarak kayır edilebildiği ve yazılım tarafından başarıyla işlendiği doğrulanmıştır. Bu testler, kamera ile Raspberry Pi arasındaki haberleşmenin kararlı ve güvenilir olduğunu göstermiştir.

## c. Şematik ve PCB Tasarım Çalışmaları

## 1. Şematik Tasarım: KiCad EDA yazılımı kullanılarak Raspberry Pi’nin 40-pin headerına uyumlu Hat formarını, ArduCAM OV2640 kamera ile ST7735 TFT ekran modülleri arasındaki bağlantıları ve LM2596S-3.3 tabanlı anahtarlamalı güç kaynağı devresini içeren bir tasarım yapılmıştır.

## 2. PCB Yerleşimi: HAT form faktörüne uygun olarak tasarlanan PCB yerleşiminde, SPI sinyallerinin kısa ve kontrollü şekilde yönlendirilmesine, güç hatlarında geniş bakır izleri kullanılmasına ve LM2596S-3.3 devresi için termal yönetimin sağlanmasına özen gösterilmiştir.

## d. Elde Edilen Nihai Çıktılar

## Final rapor aşamasına kadar elde edilen başlıca çıktılar aşağıda özetlenmiştir:

## 1. Raspberry Pi tabanlı görüntü işleme sistemlerine yönelik literatür taraması.

## 2. GitLab ve Trello platformları üzerinde oluşturulmuş proje yönetimi altyapısı.

## 3. ST7735 TFT ekran ve ArduCAM OV2640 kamera modülleri için geliştirilen bağımsız test yazılımları.

## 4. KiCad ortamında tamamlanmış ve doğrulanmış devre şematiği ve pcb dosyaları.

## 5. HAT form faktörüne uygun olarak tasarlanmış ve üretilerek lehimlenmiş PCB Hat tasarımı.

## 6. Kameradan alınarak Raspberry Pi üzerinde işlenen ve ekran üzerinde gösterilen görüntü çıktıları.

## 3.3 Kamera ve Ekran Deneme Testleri

## 1. Kamera Mimarisi ve Deneme Testleri

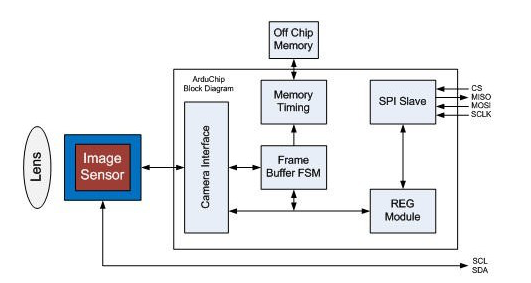
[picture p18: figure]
ArduCAM Mini 2MP image sensor OV2640

Şekil 2.1

Şekil 2.1’ de ArduCAM Mini OV2640 kamera modülünün temel mimarisi gösterilmektedir.

Sistemde, lens tarafından odaklanan görüntü OV2640 CMOS sensörüne iletilmekte ve

sensör tarafından dijitalleştirilen veri, modül içerisindeki Camera Interface birimine

aktarılmaktadır.

Görüntü verisi, ArduChip içerisinde yer alan Frame Buffer ve Memory Timing

blokları tarafından işlenerek haricî FIFO tampon belleğe yazılır. Bu yapı, sensörün piksel

zamanlaması ile dış işlemcinin veri okuma hızını uyumlu hâle getirir. Sensör

konfigürasyonuna ilişkin ayarlar (pozlama, çözünürlük, renk işleme vb.), diyagramda

gösterilen I²C (SCL/SDA) hattı üzerinden yapılmaktadır.

Dış sistem ile veri iletişimi, modülün SPI Slave arayüzü üzerinden sağlanır. Bu arayüz,

FIFO’da depolanan görüntü verilerinin SPI protokolü ile yüksek hızda okunmasına olanak

tanır. Modülün genel kontrol ve durum yönetimi ise REG Module üzerinden gerçekleştirilir.

Bu bütünleşik yapı, karmaşık sensör zamanlamasını soyutlayarak görüntü verisinin Raspberry

Pitarafından kolay ve düşük işlem yüküyle alınmasını sağlar.

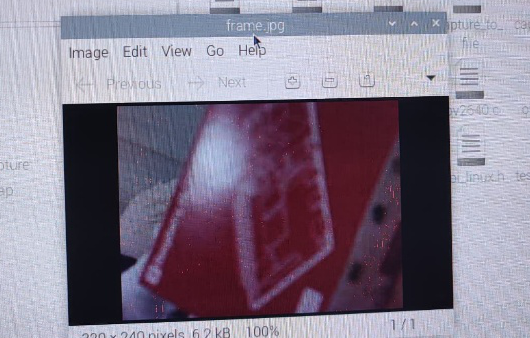
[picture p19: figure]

Şekil 2.2 Şekil 2.3

Şekil 2.2 ve Şekil 2.3’te, kameradan alınan görüntülerin SPI arayüzü üzerinden Raspberry Pi’ye aktarılarak proje dizini içerisine .jpg formatında kaydedildiği test süreci gösterilmektedir. Bu testler sonucunda, kamera ve Raspberry Pi arasındaki veri aktarımının doğru ve kararlı şekilde gerçekleştirildiği doğrulanmıştır.

2. ST7735 TFT Ekran Fonksiyon Testleri

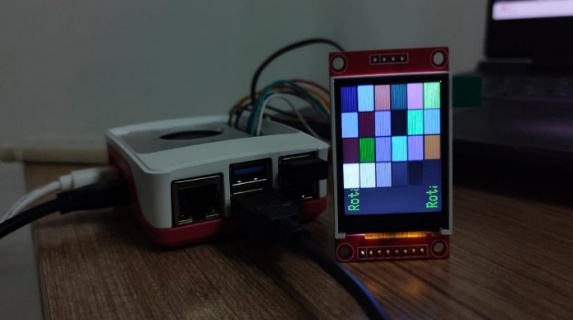
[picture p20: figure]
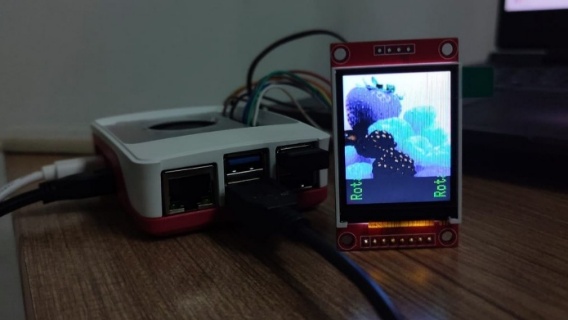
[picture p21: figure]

Şekil 3.1 Şekil 3.2

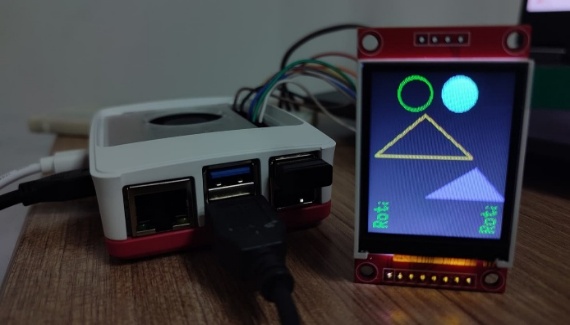
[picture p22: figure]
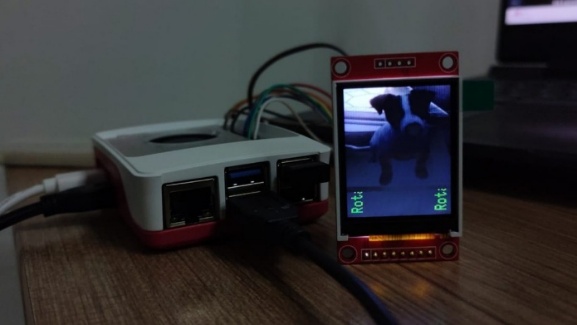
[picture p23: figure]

Şekil 3.3 Şekil 3.4

Şekil 3.[1-4]’te, ST7735 ekranın temel grafik işlevlerinin başarıyla çalıştığı görülmektedir. Bu aşamada ekran, SPI üzerinden gönderilen piksel dizilerini doğru şekilde işleyerek renkli kareler, çizgiler ve doğrulama amaçlı test desenlerini eksiksiz olarak göstermiştir. Bu test, ekran sürücüsünün doğru yapılandırıldığını, SPI iletişiminin stabil olduğunu ve RGB565 formatındaki verinin panele hatasız aktarıldığını doğrulamaktadır.

# 3.4 Şematik ve pcb tasarımı

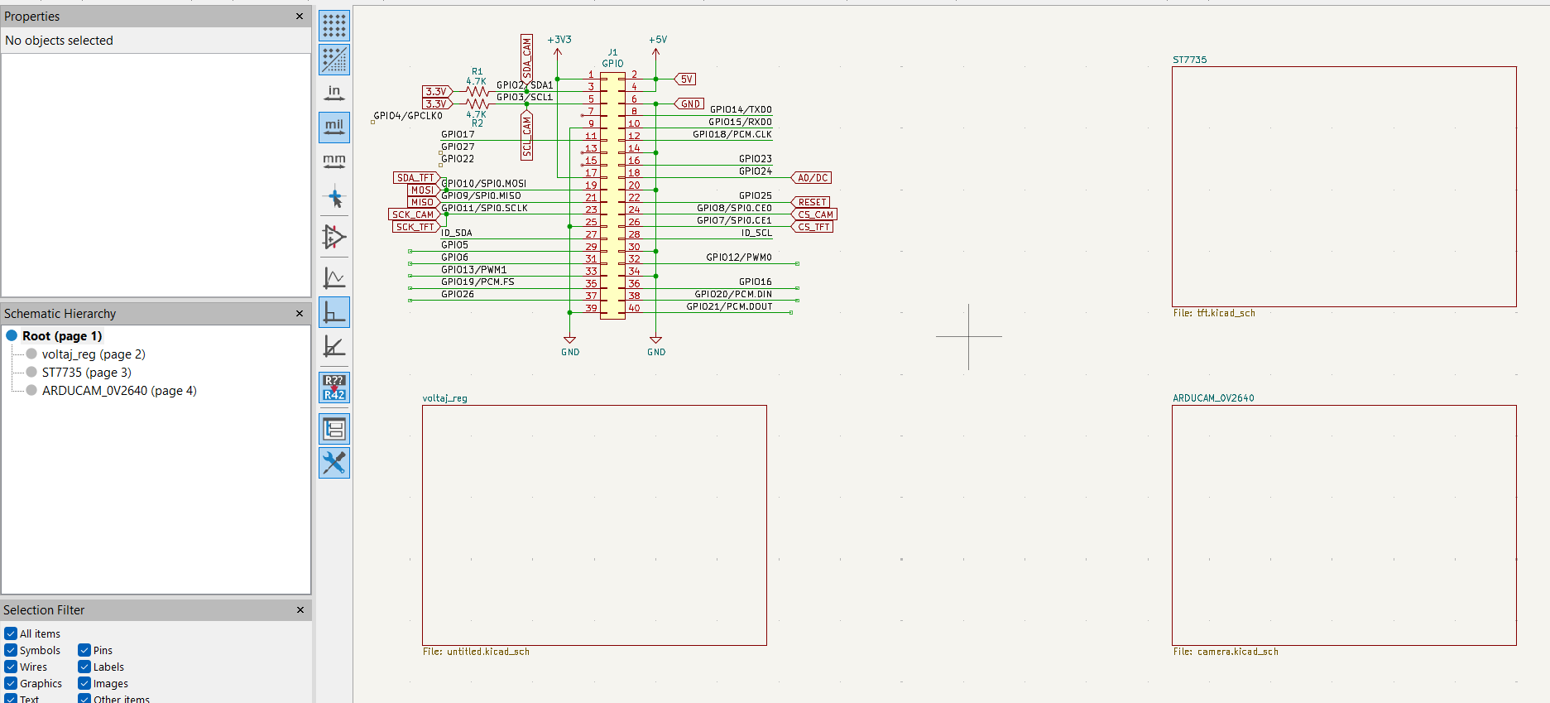
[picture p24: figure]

Şekil 5.1

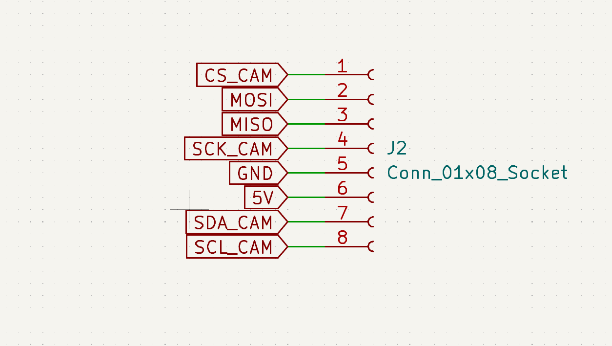
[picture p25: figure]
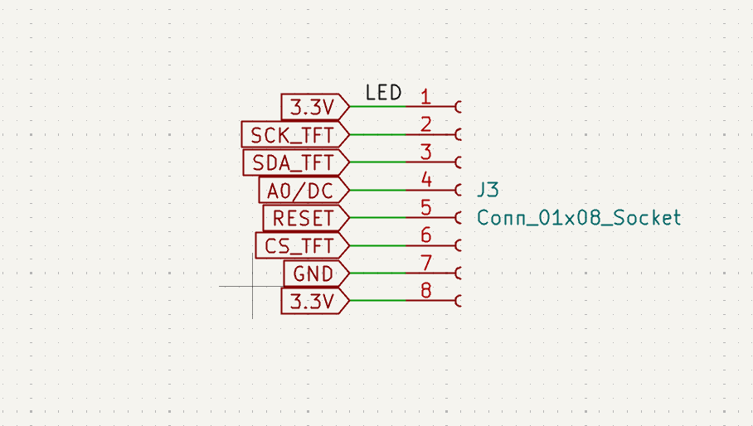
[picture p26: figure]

Şekil 5.2 Şekil 5.3

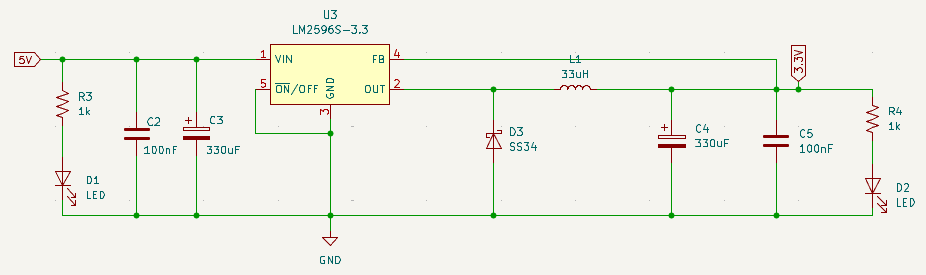
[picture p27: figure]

Şekil 5.4 Şekil 5.5

Şekil 5.[1–5]’te geliştirilen HAT kartına ait KiCad üzerinde oluşturulan devre şeması bileşenlerini göstermektedir. Şematikte Raspberry Pi’nin 40-pin GPIO başlığı, ST7735 TFT ekran bağlantıları, ArduCAM OV2640 kamera modülü ve LM2596S-3.3 tabanlı güç dönüştürücü devresi ayrı alt bloklar hâlinde yapılandırılmıştır. Raspberry Pi’den alınan SPI ve I²C hatları, kamera ve ekran modüllerine uygun şekilde yönlendirilmiş; SPI hattı her iki modül tarafından ortak kullanılırken çip seçme (CS) sinyalleri modüllere ayrı ayrı atanmıştır. Kamera sensörünün yapılandırılması için gerekli I²C hattı üzerinde pull-up dirençleri eklenmiş; güç dağıtımı bölümünde ise 5 V girişin LM2596S-3.3 devresi üzerinden kararlı 3,3 V seviyesine dönüştürülddüğü bir devre tasarımı yapılandırılmıştır.


Şekil 6.1 Şekil 6.2


Şekil 6.3 Şekil 6.4


Şekil 6.5 Şekil 6.6


Şekil 6.7 Şekil 6.8


Şekil 6.9 Şekil 6.10

Şekil 6.[1-4]’te, geliştirilen HAT kartına ait KiCad EDA kullanılarak oluşturulmuş çift katmanlı PCB tasarımı 2D ve 3D olarak gösterilmektedir. SPI sinyal hatlarının mümkün olduğunca kısa ve düzgün yönlendirilmesine özen gösterilmiş; güç hatlarında geniş bakır izler kullanılarak akım taşıma kapasitesi artırılmıştır. PCB’nin alt katmanı toprak düzlemi (GND plane) olacak şekilde tasarlanarak hem elektromanyetik gürültünün azaltılması hem de sinyal bütünlüğünün iyileştirilmesi hedeflenmiştir..

Şekil 6.[5-6]’da, KiCad ortamında tasarlanan HAT kartının JLCPCB firmasına sipariş edilmesi sonucunda teslim alınan PCB görüntüleri yer almaktadır. Üretilen PCB’lerin mekanik ölçülerinin, katman yapısının ve delik/via hizalamalarının tasarım dosyaları ile birebir uyumlu olduğu gözlemlenmiştir.

Şekil 6.[7-8]’de, üretilen PCB üzerine temin edilmiş SMD ve THT bileşenlerin lehimlenmesi sonucunda elde edilen HAT kartı gösterilmektedir. LM2596S-3.3 güç dönüştürücü devresi, Raspberry Pi GPIO header ile kamera ve TFT ekran konnektörleri karta başarıyla lehimlenmiştir. Daha sonrasında yapılan görsel ve elektriksel kontrollerde kısa devre veya lehim hatası bulunmamış ve kartın fonksiyonel testlere hazır olduğu doğrulanmıştır.

Şekil 6.[9-10]’da, geliştirilen HAT kartının Raspberry Pi platformu üzerine takılarak gerekli yazılımlar ile test edildiği ve çalıştırıldığı gösterilmektedir. Bu testler sırasında kamera modülünden alınan görüntü verilerinin Raspberry Pi tarafından başarıyla işlenerek TFT ekran üzerinde görüntülendiği gözlemlenmiştir. Elde edilen sonuçlar, geliştirilen PCB tasarımının hem mekanik hem de elektriksel olarak Raspberry Pi ile uyumlu çalıştığını ve sistem gereksinimlerini karşıladığını ortaya koymaktadır.


# 4. KAYNAKLAR

# 1. https://www.uctronics.com/download/amazon/arducam_mini_2mp_camera_shield_hardware_application_note.pdf

# 2. https://www.uctronics.com/download/amazon/arducam_mini_2mp_camera_shield_ds.pdf

# 3. https://blog.arducam.com/downloads/shields/arducam_camera_shield_software_application_note.pdf

# 4. https://jomjol.github.io/aı-on-the-edge-device-docs/datasheets/camera.ov2640_ds_1.8_.pdf

# 5. https://github.com/gavinlyonsrepo/display_lib_rpı/tree/main/extra/doc/st7735

# 6. https://github.com/arducam/arduino/tree/master/arducam

# 7. https://github.com/richgel999/picojpeg

# 8. https://github.com/arducam/pıco_spı_cam/tree/master/c/arducam

# 9. https://github.com/arducam/arduino

# 10. https://docs.arducam.com/arduino-spı-camera/legacy-spı-camera/ıntroduction/#arducam-spi-camera

# 11. https://docs.arducam.com/arduino-spı-camera/legacy-spı-camera/hardware/arducam-shield-mini-2mp-plus/#61-single-camera-wiring

# 12. https://docs.arducam.com/arduino-spı-camera/legacy-spı-camera/hardware/arducam-shield-mini-2mp-plus/#3-key-specifications

# 13. https://docs.arducam.com/arduino-spı-camera/legacy-spı-camera/hardware/arducam-chip/#register-table

# 14. https://www.ti.com/lit/ds/symlink/lm2596.pdf

# 15. https://www.ti.com/lit/an/slva630a/slva630a.pdf

# 16. https://www.alldatasheet.com/datasheet-pdf/pdf/326213/sıtronıx/st7735.html

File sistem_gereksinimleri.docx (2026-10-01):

KOCAELİ ÜNİVERSİTESİ

MÜHENDİSLİK FAKÜLTESİ


RASOBERRY Pİ GÖRÜNTÜ İŞLEME HAT PROJESİ

2025-2026 DÖNEM PROJESİ

SİSTEM GEREKSİNİMLERİ RAPORU

Öğrencinin Adı Soyadı:

Sena Sümeyye DURARSLAN

Bölümü: Elektronik ve Haberleşme Mühendisliği

Danışman: Yrd. Doç. Dr. Anıl ÇELEBİ

KOCAELİ, 2025

İÇİNDEKİLER:

1. Giriş
2. Fonksiyonel Gereksinimler
3. Donanım Gereksinimleri
4. Yazılım Gereksinimleri
5. Arayüz Gereksinimleri (I/O)

1. Giriş

Bu belge, OV2640 tabanlı ArduCAM kamera modülü kullanılarak tek kare görüntü yakalayan, bu görüntüyü Raspberry Pi üzerinde işleyerek ST7735 TFT ekran üzerinde gösteren bir Raspberry Pi HAT donanımına ait sistem gereksinimlerini tanımlar. Doküman, sistemin fonksiyonel, donanımsal, yazılımsal ve arayüz gereksinimlerini doğrulanabilir şekilde ortaya koymayı amaçlar.

2. Fonksiyonel Gereksinimler

Bir sistemin ne yapması gerektiğini tanımlayan temel gereksinimler. Sistemin kullanıcıya veya diğer sistemlere sağlaması gereken davranışları, görevleri ve işlevleri açıklar.

ID | Kullanılma Nedeni/İşlevi | Gösterim
FR-01 Sistem başlatma | Güç verildiğinde Raspberry Pi ve bağlı bileşenler başlatılacaktır. | Güç verilen Raspberry Pi’nin 40 pin headerına tasarlanan hat pcbi takıldığında ledler yanacak ve ekrana güç gelerek beyaz olacaktır.
FR-02 Görüntü Yakalama | Kullanıcı “fotoğraf çekme" komutu göderdiğinde kameradan görüntü yakalayacaktır. | Sistem, kullanıcı tarafından çalıştırıldığında OV2640 kamera modülünden tek kare görüntü yakalanacaktır.. (capture_file)
FR-03 Görüntü işleme | Raspberry Pi, alınan görüntü verisini ST7735 ekranın çözünürlüğüne ve renk formatına (örn: RGB565) uygun şekilde işleyecektir. | Çekilen görüntünün ekranda rgb formatında dosya oluşturması ile kontrol edilecektir. (decode_test)
FR-04 Görüntü Kaydı | Çekilen görüntü Raspberry Pi’nin dosya sisteminde .jpg vr rgb formatında kaydedilecektir. | Dosyanın kaydedildiği klasör kontrol edilerek .jpg vr rgb uzantılı dosyaya erişilecektir. (capture_file)
FR-05 Durum Göstergesi | Raspberry kod kontrol ekranı üzerinde “Hazır / Çekim / Kaydedildi / Hata” durumları gösterilecektir. | Kod çalıştırılan ekran üzerinde durumlar gösterilir (terminal/geanny)
FR-06 Görüntü Aktarımı | Raspberry Pi, OV2640 kameradan SPI arayüzü üzerinden alınan görüntü verilerini işleyip ST7735 TFT ekrana aktaracaktır. | Ana kod çalıştırıldığında kameradan alınan görüntü TFT ekranda gözlemlenecektir. (capture_screen)
FR-07 Reset İşlevi | Sistem yeniden başlatılacaktır. | Reset sonrası sistemin başlangıç ekranına dönmesi.
FR-08 Güç Yönetimi | Sistem, Raspberry Pi'nin 5V hattından aldığı gücü kullanarak kamera (5V) ve ekran (3.3V) için gerekli voltajları sağlayacaktır.. | Multimetre ile test edililerek doğru voltaj değerleri regülatör giriş ve çıkışında gözlemlenecektir.

3. Donanım Gereksinimleri

Bu bölümde, sistemin fiziksel olarak gerçekleştirilebilmesi için gerekli olan donanım bileşenleri tanımlanmaktadır.

ID | Bileşen/Modül | Kullanılma Nedeni/İşlevi | Gösterim
HW-01 | Raspberry Pi 4B (ana işlemci) | Sistemin ana işlem birimi olacak. SPI, I²C ve GPIO hatları üzerinden kamera, ekran ve güç hattını kontrol edecektir. | Raspberry Pi’ye güç verşlecek çalıştırılacak daha sonea bilgisayar ekranında arayüzü açılacaktır.
HW-02 | 40-pin Header | Raspberry Pi 4 ve Hat/pcb arasında fiziksel bağlantı için kullanılacaktır. | Hat tasarımı konnektörler aracılığı ile Raspberry Pi pinlerine takılarak gösterilecektir.
HW-03 | Voltaj Regülatör (LM2596) | Kameranın 5v ve ekranın 3.3v ile çalışması nedeniyle voltaj regületörü kullanılacaktır. | Multimetrenin pozitif probu LM2596'nın giriş pinine (veya giriş kondansatörüne), negatif probu ise GND'ye bağlanacaktır.
HW-04 | Bobin | Anahtarlama sırasında enerjiyi manyetik alanda depolayarak sürekli ve düzgün akım akışını sağlayacaktır | Regülatör çıkışından sabit voltaj elde edilebilmesi, indüktörün enerji transferini sağladığını gösterecektir.
HW-05 | Schottky Diyot (SS34) | Anahtarlama elemanı kapalıyken bobin enerjisinin güvenli şekilde devreye geri aktarılmasını sağlar. | Regülatörün yük altında 3.3V üretebilmesi ile doğrulanacaktir.
HW-06 | Elektrolitik Kapasitör | Giriş gerilimindeki ani akım çekişlerini sönümleyerek regülatöre stabil besleme sağlar. Çıkış voltajındaki dalgalanmayı azaltarak düzgün DC gerilim sağlar. | Yük değişimleri sırasında sistemin kesintisiz ve kararlı çalışması
HW-07 | Bypass (Decoupling) Kapasitörü | Yüksek frekanslı gürültüyü bastırarak regülatör ve yük arasındaki parazitleri azaltır. | Yüksek frekanslı anahtarlama sırasında besleme hattından beslenen dijital bileşenlerin kararlı şekilde çalışabilmesi ile doğrulanır.
HW-08 | Direnç | SDA ve SCL hatlarını lojik ‘1’ seviyesine çekerek I2C open-drain haberleşmesinin mümkün olmasını ve LED üzerinden geçen akımı sınırlayarak LED’in ve sürücü hattının zarar görmesini önleyecekt.r | Devre Raspberry Pi’ye takılı değilken Multimetre ohm konumuna getirilerek ölçülecek ve 4.7k ile 1k değerleri gözlemlenecektir.
HW-09 | Micro SD Kart | Raspberry Pi üzerinde çalışan sistem yazılımı, işletim sistemi ve çekilen görüntü dosyalarının depolanması için kullanılacaktır. | Raspberry Pi’nin SD karttan başarıyla açılması ile doğrulanacaktır.
HW-10 | OV2640 Kamera Modülü | Sistem, görüntü yakalama için OV2640 tabanlı ArduCAM Mini kamera modülünü kullanacaktır. | Kamera modülünün fiziksel olarak bağlı olduğu ve besleme aldığı doğrulanacaktır.
HW-11 | Görüntüleme ekranı (st7735) | Sistem, SPI tabanlı TFT ile görüntüleme yapacaktır. Ekran SPI0.1 hattına bağlanacaktır | Kameradan çekilen görüntü işlendikten sonra tft ekranda gözlemlenecektir.
HW-12 | Güç Led1 | Regülatör girişinde güç gözlemlendiğinde led yanacaktır. | Güç verildiğinde yeşil led’in yanmasıyla doğrulanacaktır.
HW-13 | Güç Led2 | Regülatör çıkışında güç gözlemlendiğinde led yanacaktır. | Regülatör çıkışında kırmızı led’in yanmasıyla doğrulanacaktır..
HW-14 | PCB | Sistem, Raspberry Pi’ye doğrudan takılabilen bir HAT PCB üzerinde gerçekleştirilecekt.r | Lehimlenmiş hat kart tasarımı Raspberry pi ile çalıştırıldığında pcbnin doğruluğu kontol edilir.

4. Yazılım Gereksinimleri

ID | Kullanılma Nedeni/İşlevi
SW-01 | Sistem, Linux tabanlı Raspberry Pi OS Bookworm üzerinde çalışmalıdır.
SW-02 | Kamera kontrolü I2C, görüntü verisi aktarımı SPI arayüzleri üzerinden gerçekleştirilmelidir.
SW-03 | Yazılım mimarisi; kamera başlatma, görüntü yakalama, veri aktarımı, görüntü işleme ve ekran sürme modüllerine ayrılmalıdır.
SW-04 | Görüntü işleme adımı JPEG → RGB565 dönüşümünü içermelidir.
SW-05 | Yazılım, hata durumlarında güvenli şekilde sonlanmalıdır.

5. Arayüz Gereksinimleri (I/O)

Bu bölüm, sistem alt bileşenleri arasında kullanılan haberleşme protokollerini ve pin bağlantılarını tanımlar.

ID | Arayüz | Kullanılma Nedeni | Protokol | Bağlantı Noktası
IR-01 | Kamera Kontrol | Sistem, kamera sensörünün kontrol ve konfigürasyon işlemlerini gerçekleştirebilecek bir I2C arayüzü içerecektir. | I2C | GPIO 2 (SDA), GPIO 3 (SCL)
IR-02 | Kamera Veri | Sistem, kamera modülünden görüntü verisini alabilecek bir SPI veri arayüzü içerecektir. | SPI | GPIO 10 (MOSI), GPIO 9 (MISO), GPIO 11 (SCK), GPIO 8 (CS)
IR-03 | Ekran Veri | Sistem, TFT ekran ile veri aktarımı yapabilecek bir SPI arayüzü içerecektir. | SPI | GPIO 10 (MOSI), GPIO 11 (SCK)
IR-04 | Ekran Kontrol | Sistem, TFT ekranın reset ve veri/komut kontrolünü sağlayacak GPIO hatlarını içerecektir | GPIO | GPIO 7 (CS), GPIO 25 (DC/A0), GPIO 24 (RESET)
IR-05 | Güç Girişi | | DC | Raspberry Pi 5V Pinleri
IR-06 | Güç Çıkışı | | DC | LM2596 Çıkışı (+3.3V)

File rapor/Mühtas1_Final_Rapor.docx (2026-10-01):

KOCAELİ ÜNİVERSİTESİ

MÜHENDİSLİK FAKÜLTESİ


RASPBERRY Pİ GÖRÜNTÜ İŞLEME HAT PROJESİ

MÜHTAS-1

2025-2026 1. DÖNEM PROJESİ

Öğrencinin Adı Soyadı:

Sena Sümeyye DURARSLAN

Bölümü: Elektronik ve Haberleşme Mühendisliği

Danışman: Yrd. Doç. Dr. Anıl ÇELEBİ

KOCAELİ, 2025

# İÇİNDEKİLER

1. İçindekiler ii

2. Güç Yönetiminde SMPS Kullanımının Gerekçesi……………………………… 3

3. Projede Yapılan Çalışmalar 4

3.1 Kavramsal Tasarım 4

3.2 Projede Gerçekçeşen İş Paketleri ve Ara Çıktıları 6

3.3 Kamera ve Ekran Deneme Testleri ……………………………………………… 8

3.4 Şematik Ve Pcb Tasarımı ………………………………………………………. 10

4. Kaynaklar …………………………………………………………………………14

# 1. GİRİŞ

Bu proje, Raspberry Pi 4 Model B platformu için özel olarak tasarlanmış bir HAT (Hardware Attached on Top) kartı geliştirmeyi amaçlamaktadır. Projenin temel gereksinimi, Arducam OV2640 kamera modülünden elde edilen görüntü verisini Raspberry Pi üzerinde işlemek ve elde edilen çıktıyı ST7735 TFT ekran modülü aracılığıyla görselleştirmektir.

Proje, gömülü sistemler alanında düşük maliyetli, enerji verimli ve kompakt bir görüntü işleme ve görüntüleme çözümü sunarak, özellikle robotik, uzaktan izleme ve taşınabilir görüntüleme sistemleri gibi uygulama alanlarındaki sorunları çözmeyi hedeflemektedir.

Sistemin genel yapısı, üç ana modülün Raspberry Pi'ye entegrasyonu üzerine kuruludur:

1. Görüntü Yakalama Modülü: Arducam Mini-M- OV2640
2. Görüntüleme Modülü: ST7735 TFT Ekran
3. Güç Yönetim Modülü: LM2596S-3.3 tabanlı SMPS devresi.


Şekil 1.1


Şekil 1.2

Projenin genel mimarisi, Şekil 1.1'de gösterilen blok diyagramı ile özetlenmektedir. Merkezi işlem birimi olan Raspberry Pi, sistemin ana kontrolcüsü olarak görev yapmaktadır.

Görüntü yakalama birimi olan Kamera (Arducam OV2640) ile Raspberry Pi arasındaki iletişim, hem yüksek hızlı veri transferi için SPI (SCK, MOSI, MISO, CS) hem de sensör konfigürasyonu için I²C (SDA, SCL) protokolleri üzerinden sağlanmaktadır.

Görüntüleme birimi olan Ekran (ST7735) ise Raspberry Pi'den gelen işlenmiş veriyi SPI (SCK, MOSI, CS, DC, RESET) üzerinden almaktadır. Sistemin enerji verimliliğini ve kararlılığını sağlamak amacıyla, Raspberry Pi'nin 5V hattından beslenen harici bir Regülatör (LM2596S-3.3), Kamera ve Ekran modüllerinin gerektirdiği 3.3V ve 5V besleme gerilimlerini sağlamaktadır.

Donanım entegrasyonunun temelini oluşturan pin atamaları, Şekil 1.2'de gösterilmiştir. Görüntü verisinin hızlı aktarımı için kritik olan SPI arayüzü, Raspberry Pi'nin donanımsal SPI0 hattına tahsis edilmiştir: GPIO 11 (SCK) ve GPIO 10 (MOSI) kamera ve ekran için ortak hatlar olarak kullanılmaktadır. Her iki modülün bağımsız kontrolü için GPIO 8 (CS) Kameranın Chip Select sinyaline, GPIO 7 (CS) ise Ekranın Chip Select sinyaline atanmıştır. Kamera sensörünün konfigürasyonu için I²C protokolü, Raspberry Pi'nin standart I²C1 hattı olan GPIO 2 (SDA) ve GPIO 3 (SCL) pinleri üzerinden sağlanmıştır. Ekranın komut/veri ayrımı için GPIO 25 (DC) ve donanımsal sıfırlama için GPIO 24 (RESET) pinleri kullanılarak mantıksal kontrol sağlanmıştır

2. Güç Yönetiminde SMPS Kullanımının Gerekçesi

Sistemin güç gereksinimlerini karşılamak amacıyla LM2596S-3.3 entegresi tabanlı anahtarlamalı güç kaynağı (SMPS) tercih edilmiştir. Raspberry Pi’nin 5 V besleme hattından kamera ve TFT ekran modülünün gerektirdiği 3.3 V gerilimin elde edilmesi sürecinde yüksek enerji verimliliği, düşük ısı kaybı ve kararlı çıkış gerilimi sağlanması hedeflenmiştir.

Lineer regülatör tabanlı çözümlerde, giriş ve çıkış gerilimleri arasındaki fark ısıya dönüşür. Özellikle akım tüketimi yüksek veya zamana bağlı olarak değişken olan sistemlerde ciddi güç kayıpları ve termal sorunlar ortaya çıkabilmektedir. Bu durum, hem sistemin enerji verimliliğini düşürmekte hem de uzun süreli çalışmalarda güvenilirliği olumsuz etkilemektedir.

Anahtarlamalı güç kaynakları ise enerjiyi anahtarlama elemanları aracılığıyla yüksek verimle dönüştürdüğünden, aynı güç seviyesinde lineer regülatörlere kıyasla çok daha düşük ısı kaybı oluşturmaktadır. Bu sayede, kamera ve ekran gibi ani ve değişken akım çekişine sahip modüllerin beslendiği uygulamalarda çıkış geriliminin daha kararlı tutulması mümkün olmaktadır.

Sonuç olarak, SMPS kullanımı; sistemin termal kararlılığını artırmakta, enerji verimliliğini yükseltmekte ve gömülü sistemler için kritik öneme sahip olan uzun süreli, güvenilir ve taşınabilir çalışma gereksinimlerini karşılayan bir güç yönetimi çözümü sunmaktadır.

# 3. PROJEDE YAPILAN ÇALIŞMALAR

## 3.1 Kavramsal Tasarım

Temel Aşamalar:

Sistem Analizi ve Gereksinim Belirleme

- Proje hedeflerinin tanımlanması
- Donanım/yazılım gereksinimlerinin belirlenmesi

Sistem Mimarisi Tasarımı

- Blok diyagramların oluşturulması
- Modüller arası iletişim protokollerinin belirlenmesi (SPI, I2C, GPIO vb.)
- Veri akış şemalarının tasarlanması

Donanım Tasarımı

- Komponent seçimi ve tedarik
- Devre şematiği tasarımı
- PCB tasarımı
- Breadboard/prototip kurulumu

Yazılım Geliştirme

- Test yazılımları
- Driver geliştirme (örn: kamera sürücüleri)
- Ana uygulama yazılımı

Entegrasyon ve Test

- Modül testleri
- Sistem entegrasyonu
- Performans testleri
- Hata ayıklama ve optimizasyon

Proje, donanım tasarımı, PCB üretimi ve yazılım geliştirme olmak üzere üç ana aşamada yapılandırılmıştır.

A. Donanım Tasarım Aşaması
1. Bileşen Seçimi ve Analizi: Projenin temel işlevlerini yerine getirecek Arducam OV2640, ST7735 ve LM2596S-3.3 gibi kritik bileşenlerin teknik veri sayfaları incelenmiş ve arayüz uyumlulukları (SPI, I²C) ile devre bileşen gereklilikleri doğrulanmıştır.
2. Şematik Tasarım: KiCad EDA yazılımı kullanılarak Raspberry Pi'nin 40-pin GPIO headerına uygun pin atamaları (SPI hatlarının paylaşımı, I²C pull-up dirençleri) ve LM2596S-3.3 entegresinin çevresel bileşenlerini (bobin, diyot, kapasitörler) içeren devre şeması oluşturulmuştur.
3. PCB Yerleşim Tasarımı: HAT form faktörüne uygun olarak, yüksek hızlı sinyal bütünlüğünü, güç yönetimini, ekran ve kamera konumlarını gözeten bir PCB yerleşimi tasarlanmıştır. Bu aşamada, güç hatları için geniş izler ve gnd için via'lar kullanılarak tasarım optimizasyonu yapılmıştır.

B. PCB Üretim ve Montaj Aşaması

1. PCB Üretimi: Tasarlanan Gerber dosyaları kullanılarak HAT kartının fiziksel üretimi JLCPCB firmasından sipariş edilerek gerçekleştirilmiştir..
2. Bileşen Montajı: SMD bileşenleri (LM2596S-3.3, dirençler, kapasitörler, bobin, diyot) ve header'lar PCB üzerine lehimlenerek HAT tasarım kartı oluşturulmuştur.

C. Yazılım Geliştirme ve Entegrasyon Aşaması

1. Sürücü Geliştirme: Raspberry Pi OS üzerinde C/C++ programlama dili kullanılarak, Arducam OV2640 için I²C üzerinden konfigürasyon ve SPI üzerinden veri okuma sürücüleri geliştirilecektir. Aynı zamanda ST7735 ekran için SPI üzerinden komut ve piksel verisi gönderme işlevleri programlanacaktır.
2. Görüntü İşleme Algoritması: Kameradan alınan JPEG formatındaki veriyi çözmek ve ST7735 ekranın gerektirdiği RGB565 formatına dönüştürmek için bir görüntü işleme algoritması uygulanacaktır.
3. Sistem Entegrasyonu ve Test: Geliştirilen donanım ve yazılım birleştirilerek, sistemin görüntü yakalama, işleme ve görüntüleme işlevlerini beklenen performans ve stabilite ile yerine getirip getirmediği adım adım test kodlarıyla Makefile dosyası üzerinden kontrol edilecektir.

## 3.2 Projede Gerçekçeşen İş Paketleri ve Ara Çıktıları

Projenin final rapor dönemine kadar olan sürecinde, donanım tasarımı ve yazılım geliştirme aşamaları tamamlanmış; sistemin temel mimarisi, donanım-yazılım entegrasyonu ve fonksiyonel testleri başarıyla gerçekleştirilmiştir. Bu bölümde, proje kapsamında yürütülen iş paketleri ve elde edilen somut çıktılar sunulmaktadır.

## a. Literatür Taraması ve Proje Hazırlığı

Proje başlangıcında, benzer görüntü işleme uygulamaları üzerine bir literatür taraması yapılmıştır. Ayrıca, projenin etkin yönetimi için GitLab (versiyon kontrolü-kod depolama-proje görseleri-Kicad dosyaları vb.) ve Trello (görev takibi-iş akışı yönetimi-toplantı notları vb.) gibi proje yönetim araçlarının kullanımı araştırılmıi ve kullanılmıştır. Görev takibi yoğunluklu olarak Trello üzerinden yapılmıştır.

## b. Ayrık Modül Testleri

## Sistem entegrasyonuna geçilmeden önce, kritik donanım modüllerinin Raspberry Pi platformu ile ayrı ayrı testi gerçekleştirilmiştir. Bu yaklaşım, entegrasyon aşamasında oluşabilecek hataların erken tespit edilmesini sağlamıştır.

## 1. ST7735 TFT Ekran Testleri: ST7735 ekran modülüne SPI arayüzü üzerinden test desenleri ve grafik verileri gönderilerek ekran sürücüsünün doğru çalıştığı doğrulanmıştır.

2. ArduCAM OV2640 Kamera Testleri:
OV2640 kamera modülünün I²C arayüzü üzerinden sensör konfigürasyonu ve SPI arayüzü üzerinden görüntü verisi aktarımı test edilmiştir. Kamera tarafından üretilen JPEG formatındaki görüntü verilerinin Raspberry Pi’ye hatasız şekilde aktarılarak kayır edilebildiği ve yazılım tarafından başarıyla işlendiği doğrulanmıştır. Bu testler, kamera ile Raspberry Pi arasındaki haberleşmenin kararlı ve güvenilir olduğunu göstermiştir.

## c. Şematik ve PCB Tasarım Çalışmaları

## 1. Şematik Tasarım: KiCad EDA yazılımı kullanılarak Raspberry Pi’nin 40-pin headerına uyumlu Hat formarını, ArduCAM OV2640 kamera ile ST7735 TFT ekran modülleri arasındaki bağlantıları ve LM2596S-3.3 tabanlı anahtarlamalı güç kaynağı devresini içeren bir tasarım yapılmıştır.

## 2. PCB Yerleşimi: HAT form faktörüne uygun olarak tasarlanan PCB yerleşiminde, SPI sinyallerinin kısa ve kontrollü şekilde yönlendirilmesine, güç hatlarında geniş bakır izleri kullanılmasına ve LM2596S-3.3 devresi için termal yönetimin sağlanmasına özen gösterilmiştir.

## d. Elde Edilen Nihai Çıktılar

## Final rapor aşamasına kadar elde edilen başlıca çıktılar aşağıda özetlenmiştir:

## 1. Raspberry Pi tabanlı görüntü işleme sistemlerine yönelik literatür taraması.

## 2. GitLab ve Trello platformları üzerinde oluşturulmuş proje yönetimi altyapısı.

## 3. ST7735 TFT ekran ve ArduCAM OV2640 kamera modülleri için geliştirilen bağımsız test yazılımları.

## 4. KiCad ortamında tamamlanmış ve doğrulanmış devre şematiği ve pcb dosyaları.

## 5. HAT form faktörüne uygun olarak tasarlanmış ve üretilerek lehimlenmiş PCB Hat tasarımı.

## 6. Kameradan alınarak Raspberry Pi üzerinde işlenen ve ekran üzerinde gösterilen görüntü çıktıları.

## 3.3 Kamera ve Ekran Deneme Testleri

## 1. Kamera Mimarisi ve Deneme Testleri

ArduCAM Mini 2MP image sensor OV2640

Şekil 2.1

Şekil 2.1’ de ArduCAM Mini OV2640 kamera modülünün temel mimarisi gösterilmektedir.

Sistemde, lens tarafından odaklanan görüntü OV2640 CMOS sensörüne iletilmekte ve

sensör tarafından dijitalleştirilen veri, modül içerisindeki Camera Interface birimine

aktarılmaktadır.

Görüntü verisi, ArduChip içerisinde yer alan Frame Buffer ve Memory Timing

blokları tarafından işlenerek haricî FIFO tampon belleğe yazılır. Bu yapı, sensörün piksel

zamanlaması ile dış işlemcinin veri okuma hızını uyumlu hâle getirir. Sensör

konfigürasyonuna ilişkin ayarlar (pozlama, çözünürlük, renk işleme vb.), diyagramda

gösterilen I²C (SCL/SDA) hattı üzerinden yapılmaktadır.

Dış sistem ile veri iletişimi, modülün SPI Slave arayüzü üzerinden sağlanır. Bu arayüz,

FIFO’da depolanan görüntü verilerinin SPI protokolü ile yüksek hızda okunmasına olanak

tanır. Modülün genel kontrol ve durum yönetimi ise REG Module üzerinden gerçekleştirilir.

Bu bütünleşik yapı, karmaşık sensör zamanlamasını soyutlayarak görüntü verisinin Raspberry

Pitarafından kolay ve düşük işlem yüküyle alınmasını sağlar.


Şekil 2.2 Şekil 2.3

Şekil 2.2 ve Şekil 2.3’te, kameradan alınan görüntülerin SPI arayüzü üzerinden Raspberry Pi’ye aktarılarak proje dizini içerisine .jpg formatında kaydedildiği test süreci gösterilmektedir. Bu testler sonucunda, kamera ve Raspberry Pi arasındaki veri aktarımının doğru ve kararlı şekilde gerçekleştirildiği doğrulanmıştır.

2. ST7735 TFT Ekran Fonksiyon Testleri


Şekil 3.1 Şekil 3.2


Şekil 3.3 Şekil 3.4

Şekil 3.[1-4]’te, ST7735 ekranın temel grafik işlevlerinin başarıyla çalıştığı görülmektedir. Bu aşamada ekran, SPI üzerinden gönderilen piksel dizilerini doğru şekilde işleyerek renkli kareler, çizgiler ve doğrulama amaçlı test desenlerini eksiksiz olarak göstermiştir. Bu test, ekran sürücüsünün doğru yapılandırıldığını, SPI iletişiminin stabil olduğunu ve RGB565 formatındaki verinin panele hatasız aktarıldığını doğrulamaktadır.

# 3.4 Şematik ve pcb tasarımı


Şekil 5.1


Şekil 5.2 Şekil 5.3


Şekil 5.4 Şekil 5.5

Şekil 5.[1–5]’te geliştirilen HAT kartına ait KiCad üzerinde oluşturulan devre şeması bileşenlerini göstermektedir. Şematikte Raspberry Pi’nin 40-pin GPIO başlığı, ST7735 TFT ekran bağlantıları, ArduCAM OV2640 kamera modülü ve LM2596S-3.3 tabanlı güç dönüştürücü devresi ayrı alt bloklar hâlinde yapılandırılmıştır. Raspberry Pi’den alınan SPI ve I²C hatları, kamera ve ekran modüllerine uygun şekilde yönlendirilmiş; SPI hattı her iki modül tarafından ortak kullanılırken çip seçme (CS) sinyalleri modüllere ayrı ayrı atanmıştır. Kamera sensörünün yapılandırılması için gerekli I²C hattı üzerinde pull-up dirençleri eklenmiş; güç dağıtımı bölümünde ise 5 V girişin LM2596S-3.3 devresi üzerinden kararlı 3,3 V seviyesine dönüştürülddüğü bir devre tasarımı yapılandırılmıştır.


Şekil 6.1 Şekil 6.2


Şekil 6.3 Şekil 6.4


Şekil 6.5 Şekil 6.6


Şekil 6.7 Şekil 6.8


Şekil 6.9 Şekil 6.10

Şekil 6.[1-4]’te, geliştirilen HAT kartına ait KiCad EDA kullanılarak oluşturulmuş çift katmanlı PCB tasarımı 2D ve 3D olarak gösterilmektedir. SPI sinyal hatlarının mümkün olduğunca kısa ve düzgün yönlendirilmesine özen gösterilmiş; güç hatlarında geniş bakır izler kullanılarak akım taşıma kapasitesi artırılmıştır. PCB’nin alt katmanı toprak düzlemi (GND plane) olacak şekilde tasarlanarak hem elektromanyetik gürültünün azaltılması hem de sinyal bütünlüğünün iyileştirilmesi hedeflenmiştir..

Şekil 6.[5-6]’da, KiCad ortamında tasarlanan HAT kartının JLCPCB firmasına sipariş edilmesi sonucunda teslim alınan PCB görüntüleri yer almaktadır. Üretilen PCB’lerin mekanik ölçülerinin, katman yapısının ve delik/via hizalamalarının tasarım dosyaları ile birebir uyumlu olduğu gözlemlenmiştir.

Şekil 6.[7-8]’de, üretilen PCB üzerine temin edilmiş SMD ve THT bileşenlerin lehimlenmesi sonucunda elde edilen HAT kartı gösterilmektedir. LM2596S-3.3 güç dönüştürücü devresi, Raspberry Pi GPIO header ile kamera ve TFT ekran konnektörleri karta başarıyla lehimlenmiştir. Daha sonrasında yapılan görsel ve elektriksel kontrollerde kısa devre veya lehim hatası bulunmamış ve kartın fonksiyonel testlere hazır olduğu doğrulanmıştır.

Şekil 6.[9-10]’da, geliştirilen HAT kartının Raspberry Pi platformu üzerine takılarak gerekli yazılımlar ile test edildiği ve çalıştırıldığı gösterilmektedir. Bu testler sırasında kamera modülünden alınan görüntü verilerinin Raspberry Pi tarafından başarıyla işlenerek TFT ekran üzerinde görüntülendiği gözlemlenmiştir. Elde edilen sonuçlar, geliştirilen PCB tasarımının hem mekanik hem de elektriksel olarak Raspberry Pi ile uyumlu çalıştığını ve sistem gereksinimlerini karşıladığını ortaya koymaktadır.


# 4. KAYNAKLAR

# 1. https://www.uctronics.com/download/amazon/arducam_mini_2mp_camera_shield_hardware_application_note.pdf

# 2. https://www.uctronics.com/download/amazon/arducam_mini_2mp_camera_shield_ds.pdf

# 3. https://blog.arducam.com/downloads/shields/arducam_camera_shield_software_application_note.pdf

# 4. https://jomjol.github.io/aı-on-the-edge-device-docs/datasheets/camera.ov2640_ds_1.8_.pdf

# 5. https://github.com/gavinlyonsrepo/display_lib_rpı/tree/main/extra/doc/st7735

# 6. https://github.com/arducam/arduino/tree/master/arducam

# 7. https://github.com/richgel999/picojpeg

# 8. https://github.com/arducam/pıco_spı_cam/tree/master/c/arducam

# 9. https://github.com/arducam/arduino

# 10. https://docs.arducam.com/arduino-spı-camera/legacy-spı-camera/ıntroduction/#arducam-spi-camera

# 11. https://docs.arducam.com/arduino-spı-camera/legacy-spı-camera/hardware/arducam-shield-mini-2mp-plus/#61-single-camera-wiring

# 12. https://docs.arducam.com/arduino-spı-camera/legacy-spı-camera/hardware/arducam-shield-mini-2mp-plus/#3-key-specifications

# 13. https://docs.arducam.com/arduino-spı-camera/legacy-spı-camera/hardware/arducam-chip/#register-table

# 14. https://www.ti.com/lit/ds/symlink/lm2596.pdf

# 15. https://www.ti.com/lit/an/slva630a/slva630a.pdf

# 16. https://www.alldatasheet.com/datasheet-pdf/pdf/326213/sıtronıx/st7735.html

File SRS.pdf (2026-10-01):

## System Requirements Specification

AMAÇ: Raspberry Pi’nin 40 pinlik headerı üstüne takılıp çıkarılacak bir HAT tasarlamak.

Sistem, bir kamera modülünden alınan görüntünün Raspberry Pi üzerinden işlenip ekrana aktarılmasını amaçlar. Ayrıca ilerleyen aşamalarda FPGA üzerinde de kullanılabilir şekilde tasarlanmayı amaçlar.

Donanım Gereksinimleri:

- VGA çözünürlüklü bir kamera modülü(OV7670 / OV2640)
- MCU(?)
- Raspberry Pi (işleme+kontrol)
- TFT ekran (ST7735)
- Güç beslemesi

Yazılım Gereksinimleri:

- Kamera görüntüsünü yakalamak
- MCU kullanılması durumunda görüntüyü R-Pi’nin portlarından haberleşebileceği hale getirmek
- Görüntüyü SPI portları üzerinden R-Pi’ye veriyi gönderme
- Görüntüyü çözünürlük küçültme/ölçekeleme yaparak işleme
- Ekranda gösterme


OV7670, 640×480 (VGA) çözünürlükte görüntü alabilen, 8-bit paralel veri çıkışı (D0–D7), senkronizasyon sinyalleri (PCLK, HREF, VSYNC) ve SCCB (I²C) konfigürasyon hattı bulunan bir CMOS görüntü sensörüdür.

Format | Çözünürlük | Piksel Sayısı | Yaklaşık Veri (RGB565)
QQVGA | 160×120 | 19.200 | ≈ 38 KB
QVGA | 320×240 | 76.800 | ≈ 150 KB
VGA | 640×480 | 307.200 | ≈ 600 KB

QQVGA, QVGA’nın dörtte biri çözünürlükte olduğundan daha hızlı işlenir ve küçük mikrodenetleyiciler için uygundur sonucuna varılmıştır.

PROJE ARAŞTIRMASI YAPILIRKEN BELİRLENEN GEREKSİNİMLER VE NEDENLERİ:

Raspberry Pi kartlarında kamera kullanımı için özelleştirilmiş CSI portu bulunmaktadır ancak proje kapsamında tasarladığımız kart üzerinde bulunan GPIO pinleri üzerinden görüntü aktarımı sağlamak istediğimiz için bu portu kullanamıyoruz. Yapılan araştırılmalar sonucunda Raspberry Pi ile CSI olmayan kameraların kullanıldığı durumlara örnek bulunamamıştır, yapılan projeler genel olarak pico ile yapılmıştır.. Bunun sebeplerinden bazıları:

1. CSI bağlantısı, kameradan doğrudan Raspberry Pi’nin GPU’suna yüksek hızlı veri aktarımı sağlar. USB veya GPIO üzerinden bağlanan kameralar ise bu hızı sunamaz. Kamera modülleri saniyede milyonlarca piksel verisi (24MHZ) üretir. GPIO pinleri ise bu kadar yüksek hızda paralel veri aktarımı için tasarlanmamıştır.
Sonuç: Gecikme, bozulmuş görüntü veya veri kaybı yaşanabilir.
2. CSI hattı kullanıldığında veri doğrudan GPU tarafından alınır. GPIO üzerinden veri okuma denemelerinde ise CPU sürekli pinleri okur ("polling" veya "interrupt" yöntemiyle). Bu, CPU’nun büyük kısmını meşgul eder ve diğer işlemler yavaşlar ve video işleme, akış gibi uygulamalarda sistem kitlenebilir.
3. Linux çekirdeği GPIO üzerinden kamera veri alımı için hazır sürücü içermez.Bu sebeple kendi driverımızı yazmamız gerekir.

Yapılan incelemeler sonucu VGA kameralarıın paralel portlar üzerinden görüntüyü aktardığı görülmüştür fakat Raspberry Pi’nin GPIO pinlerinin mevcut örnekleme frekansı kernel yapısı doğrultusunda 1MHZ ‘a kadar çıkabildiği daha yüksek frekanslara çıkabilmesi için Kernel yapsısının manipüle edilmesi gerektiği saptanmıştır. Bu doğrıltuda gelen görüntüyü arada bufferlayarak pararel porttan alarak Spı portuna dönüştüren MCU devresi konulması öngörülmüştür.

SPI çıkışına sahip kameraların yüksek maaliyetli olduğu belirlenmiş ve bunun yerine maaliyet olarak daha etkin olan mcu eklenmiş devrenin kullanılması öngörülmüştür.

Rapberry Pi’nin forum sitesinde ( https://forums.raspberrypi.com/viewtopic.php?t=73190 ve https://forums.raspberrypi.com/viewtopic.php?t=11839 ) bu konu hakkında tartışmalar yapıldığı ve farklı öneriler olduğu belirlenmiş ve araştırma yapılmıştır.

Araştırma sonucu bulunan yöntemler:

- Arducam 2MP OV2640 Mini Kamera Modülü kullanarak doğrudan SPI üzerinden haberleşme sağlanabilir. OV2640/OV7670 gibi kameralar 8 bitlik paralel veri gönderdiği ve R-Pi seri veri işlediği için problem yaşanabilmektedir. Bu modül kullanıcıya alternatif bir seçenek sunuyor. Kendi sitesinde ‘Arduino, Raspberry Pi, STM32, BeagleBone Black gibi SPIve I2C arayüzüne sahip tüm platformlarla uyumludur.’ ibaresi yer alıyor.

https://www.uctronics.com/download/Amazon/ArduCAM_Mini_2MP_Camera_Shield_DS.pdf


- OV7670 + MCU (stm32/esp32/arduino) Kamera sensörleri paralel veri üretiyor ama R-Pi’nin GPIO pinleri paralel veriyi o hızda doğrudan işleyemiyor ve donanımında DCMI birimi yok bu sebeple araya MCU’yu araya ekleyerek kameradan gelen veriyi Pi’nin anlayacağı yavaş, seri bir protokole çevirmeyi hedefleyebiliriz. Böylece R-Pi sadece yüksek seviye işlemi (görüntü gösterme, kaydetme, işleme) yapar; düşük seviye kamera iletişimi MCU tarafından yönetilir. Yani bu yolda MCU köprü görevi görüyor ancak burda da drive sorunu oluyor kendimizin driver yazması gerekecek ya da hazır kaynak örneklerden drive kütüphanesi eklenebilir.
Bu yöntem seçilirse stm için Kristal, direnç,kapasitör gibi system gereçleri eklemek gerekecektir. MCU’ya kod atmak için gerekli pinlere header konularak gerekli bağlantılar yapılacak olmalıdır ve yapılabilirliği araştırılıp MCU kartı tasarlanarak tak çıkar şeklinde de yapılabilir. Kamera ve R-Pi haberleşmesi için ilgili bacaklardan gerekli pinlere yollar pcb üzerinde çizilecektir. Ama ileride FBGA kullanma durumu için kameradan görüntünün MCU’ya gitmediği ek bir yol çizilebilir yönlendirmeyi kendimizin seçebileceği.

Bu seçeneğin yapılabilirliğini elimde bulunan STM32F407 board ile deneyebiliriim. Raspberyy Pico ile yapılan örneklerde bulunmaktadır.

Kamera → MCU → Pi (görüntü verisi) → ST7735 ekran


- Raspberry Pi DMA+GPIO kamera-gpıo(dma)-frame buffer-opencv-ekran şeklinde nir yöntem kullanılabilir. Bu durumda ek bir donanıma gerek kalmaz tamamen Pi üzerinden HAT tasarımını kontrol edebilirim. Bu yönyemin de kendi içinde avantaj ve dezevantajları bulunuyor: GPIO hız sınırlaması nedeniyle FPS düşük olabilirr ve DMA ayarları gerekir. Frame buffer = pixel pixel veriyi alıp kaç tane pixel varsa TFT ekranda aynı şekilde basıyorsun. Toplam pixelimi arrayda tutuyorum (1000 pixel geliyorsa 1000’lik arrayda tuttum) daha sonra ekrana basıyorum. Ekran 2000 pixellik bir ekranda 2 pixele 1 tane pixeli basıyoruz gibi bir algoritma düzenleyebiliriz.
OV7670 datasheet’e göre nominal XCLK ~24 MHz (tipik 10–24 MHz). Pi’den GPCLK0 ile daha düşük XCLK (≈8–10 MHz) verip, sensörün PCLK’ini (clock divider/PLL) ≈1–2 MHz bandına indiririz. Bu, Linux jitter ve GPIO sınırlamalarıyla güvenli bir çalışma bölgesidir. QQVGA,RGB565

- USB Kamera kullanılabilir ancak maliyet açısından yüksek bütçeli bir yöntem

Bu durumlar karşılaştırıldığında hepsinin avantaj ve dezavantajları bulunmaktadır. DMA seçeneğinde 1Mhz örnek alma seçeneği olduğu ve daha fazla örnekleme alınması istendiğinde Kernelın kodlarına inerek müdahale edilmesi gerektiği saptandığı için bu durum daha fazla yazılım maaliyeti ve ek iş süresi demektir. R-Pi(pico harici) ile yapılan örnek projeleri bulamadığım GPIO üzerinden veri alınmak istendiğinde kameraya ait driver sürücülerini R-Pi ye port etmek gerekiyor diye düşünmekteyim. Ana amacımız donanım tasarlamak olduğu için bu seçenek taslak olarak sunulmuş ve MCU devresi tasarlanacak şekilde bir taslak şema oluşturulmuştur.

Proje kapsamında donanıma dikkat edileceği için ona göre tasarım örneği sunulmuştur.

Mimari | Açıklama | Donanım Maliyeti | Maliyeti Yazılım | Performans | Modüle edilebilirlik | Zorluk Derecesi | Not
Arducam (OV2640) | SPI üzerinden doğrudan Pi bağlantısı | Orta,Yüksek | Düşük | Yüksek | Orta | Kolay | Hazır modül, tak-çalıştır
OV7670 + STM32 MCU | Paralel veriyi SPI’ye çevirir | Düşük | Orta | Orta | Yüksek | Orta-zor | Esnek, FPGA’ya uyarlanabilir
DMA + GPIO | Pi GPIO’larıyla doğrudan okuma | Düşük | Yüksek | Düşük | Düşük | Zor | Kernel müdahalesi gerekebilir
USB Kamera | Hazır USB sürücü | Yüksek | Düşük | Yüksek | Düşük | Kolay | proje amacına uygun değil

Bu doğrultuda devre için gerekli olan alt componentlere girmeden ana componentler belirlenmiştir. Devre modeli toplantıda belirlendikten sonra devre için gerekli olan componentler çıkartılacaktır ve buna bağlı olarak maaliyet hesabı yapılacaktır.

İlgili üretim devre tasarımı yapıldıktan sonra çinde ya da Türkiye’de bulunan firmalardan fiyat/süre bilgisi alındıktan sonra üretime gönderilecektir

- https://electronics.stackexchange.com/questions/678277/how-can-i-connect-the-dvp-camera-output-with-raspberry-pi-or-other-mcu (https://electronics.stackexchange.com/questions/678277/how-can-i-connect-the-dvp-camera-output-with-raspberry-pi-or-other-mcu)


TASLAK TASARIM:

Test aşaması:

- Donanım hatlarının kontrolü
Kartlar ve bağlantıların doğru çalıştığından emin olmak.
Güç testi, Pin kontrolü vb. Kameradan veri gelip gelmediği osiloskop ile test edilebilir.
- Elektriksel doğrulamalar
Voltaj vb.kontrol
- Yazılımsal Doğrulama
Iletişim ve veri akışı doğrulama
- Sistemsel Testler
Canlı görüntü testi, FPS ölçümü vb.

Test aşaması(MCU kullanımı durumunda ):

1. Elimde STMF407 kart bulunduğu için kamera ve TFT ekran sipariş edilecek daha sonra kameradan alınan görüntü ekranda stm üzerinden oluşturulacak ve bu test ile kamera ile Stm arasına kodun doğruluğu test edilmiş olacağı planlanmaktadır.
2. Bu doğrulama sonrası STM’den gelen görüntü verilerini R-Pi üzerinden ekranda gözlemlenmek isteniyor.

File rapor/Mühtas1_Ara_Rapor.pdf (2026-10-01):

KOCAELİ ÜNİVERSİTESİ
MÜHENDİSLİK FAKÜLTESİ


RASOBERRY Pİ GÖRÜNTÜ İŞLEME HAT PROJESİ

| DÖNEM PROJESİ

Öğrencinin Adı Soyadı:
Sena Sümeyye DURARSLAN

Bölümü: Elektronik ve Haberleşme Mühendisliği

Danışman: Yrd. Doç. Dr. Anıl ÇELEBİ

KOCAELİ, 2025

ii

İÇİNDEKİLER

2.3 Kamera Mimarisi Ve Deneme Testleri |
2.4 Şematik Ve Pcb Tasarımı |

GİRİŞ

Bu proje, Raspberry Pi 4 Model B platformu için özel olarak tasarlanmış bir HAT (Hardware Attached on Top) kartı geliştirmeyi amaçlamaktadır. Projenin temel gereksinimi, Arducam OV2640 kamera modülünden elde edilen görüntü verisini Raspberry Pi üzerinde işlemek ve elde edilen çıktıyı ST7735 TFT ekran modülü aracılığıyla gerçek zamanlıya yakın bir performansla görselleştirmektir.

Proje, gömülü sistemler alanında düşük maliyetli, enerji verimli ve kompakt bir görüntü işleme ve görüntüleme çözümü sunarak, özellikle robotik, uzaktan izleme ve taşınabilir görüntüleme sistemleri gibi uygulama alanlarındaki sorunları çözmeyi hedeflemektedir.

Sistemin genel yapısı, üç ana modülün Raspberry Pi'ye entegrasyonu üzerine kuruludur:
1. 1.Görüntü Yakalama Modülü: Arducam OV2640
2. 2.Görüntüleme Modülü: ST7735 TFT Ekran
3. 3.Güç Yönetim Modülü: Yüksek verimli LM2596S-3.3 tabanlı SMPS devresi.


Şekil 1.1


Şekil 1.2

Projenin genel mimarisi, Şekil 1.1'de gösterilen blok diyagramı ile özetlenmektedir. Merkezi

işlem birimi olan Raspberry Pi, sistemin ana kontrolcüsü olarak görev yapmaktadır.

Görüntü yakalama birimi olan Kamera (Arducam OV2640) ile Raspberry Pi arasındaki

iletişim, hem yüksek hızlı veri transferi için SPI (SCK, MOSI, MISO, CS) hem de sensör

konfigürasyonu için I²C (SDA, SCL) protokolleri üzerinden sağlanmaktadır.

Görüntüleme birimi olan Ekran (ST7735) ise Raspberry Pi'den gelen işlenmiş veriyi SPI

(SCK, MOSI, CS, DC, RESET) üzerinden almaktadır. Sistemin enerji verimliliğini ve

kararlılığını sağlamak amacıyla, Raspberry Pi'nin 5V hattından beslenen harici bir Regülatör

(LM2596S-3.3), Kamera ve Ekran modüllerinin gerektirdiği 3.3V ve 5V besleme gerilimlerini

sağlamaktadır.

Donanım entegrasyonunun temelini oluşturan pin tahsisleri, Şekil 1.2'de gösterilmiştir.

Görüntü verisinin hızlı aktarımı için kritik olan SPI arayüzü, Raspberry Pi'nin donanımsal

SPI0 hattına tahsis edilmiştir: GPIO 11 (SCK) ve GPIO 10 (MOSI) ortak hatlar olarak

kullanılmaktadır. Her iki modülün bağımsız kontrolü için GPIO 8 (CS) Kameraya, GPIO 7

(CS) ise Ekranın Chip Select sinyaline atanmıştır. Kamera sensörünün kayıt konfigürasyonu

için I²C protokolü, Raspberry Pi'nin standart I²C1 hattı olan GPIO 2 (SDA) ve GPIO 3 (SCL)

pinleri üzerinden sağlanmıştır. Ekranın komut/veri ayrımı için GPIO 25 (DC) ve donanımsal

sıfırlama için GPIO 24 (RESET) pinleri kullanılarak mantıksal kontrol sağlanmıştır

### 2 PROJEDE YAPILAN ÇALIŞMALAR

### 2.1 Kavramsal Tasarım

Temel Aşamalar:

Sistem Analizi ve Gereksinim Belirleme

- Proje hedeflerinin tanımlanması
- Donanım/yazılım gereksinimlerinin belirlenmesi

Sistem Mimarisi Tasarımı

- Blok diyagramların oluşturulması
- Modüller arası iletişim protokollerinin belirlenmesi (SPI, I2C, GPIO vb.)
- Veri akış şemalarının tasarlanması

Donanım Tasarımı

- Komponent seçimi ve tedarik
- Devre şematiği tasarımı
- PCB tasarımı
- Breadboard/prototip kurulumu

Yazılım Geliştirme

- Test yazılımları
- Driver geliştirme (örn: kamera sürücüleri)
- Ana uygulama yazılımı

Entegrasyon ve Test

- Modül testleri
- Sistem entegrasyonu
- Performans testleri
- Hata ayıklama ve optimizasyon

Proje, donanım tasarımı, PCB üretimi ve yazılım geliştirme olmak üzere üç ana aşamada

yapılandırılmıştır.

A. Donanım Tasarım Aşaması
1. Bileşen Seçimi ve Analizi: Projenin temel işlevlerini yerine getirecek Arducam OV2640,

ST7735 ve LM2596S-3.3 gibi kritik bileşenlerin teknik veri sayfaları incelenmiş ve arayüz

uyumlulukları (SPI, I²C) doğrulanmıştır.

2. Şematik Tasarım: KiCad EDA yazılımı kullanılarak Raspberry Pi'nin 40-pin GPIO

başlığına uygun pin tahsisleri (SPI hatlarının paylaşımı, I²C pull-up dirençleri) ve

LM2596S-3.3 entegresinin çevresel bileşenleri (bobin, diyot, kapasitörler) içeren detaylı

devre şeması oluşturulmuştur.

3. PCB Yerleşim Tasarımı: HAT form faktörüne uygun olarak, yüksek hızlı sinyal

bütünlüğünü (SPI) ve termal yönetimi (LM2596) gözeten bir PCB yerleşimi (layout)

tasarlanmıştır. Bu aşamada, güç hatları için geniş izler ve LM2596 için termal via'lar

kullanılarak tasarım optimizasyonu yapılmıştır.

B. PCB Üretim ve Montaj Aşaması
1. PCB Üretimi: Tasarlanan Gerber dosyaları kullanılarak HAT kartının fiziksel üretimi

gerçekleştirilecektir.

2. Bileşen Montajı: SMD bileşenleri (LM2596S-3.3, dirençler, kapasitörler) ve header'lar

PCB üzerine lehimlenerek prototip kartı oluşturulacaktır.

C. Yazılım Geliştirme ve Entegrasyon Aşaması
1. Düşük Seviyeli Sürücü Geliştirme: Raspberry Pi OS üzerinde C/C++ programlama dili

kullanılarak, Arducam OV2640 için I²C üzerinden konfigürasyon ve SPI üzerinden veri

okuma sürücüleri geliştirilecektir. Aynı zamanda ST7735 ekran için SPI üzerinden komut

ve piksel verisi gönderme işlevleri programlanacaktır.
2. Görüntü İşleme Algoritması: Kameradan alınan JPEG formatındaki veriyi çözmek

(dekompresyon) ve ST7735 ekranın gerektirdiği RGB565 formatına dönüştürmek için

yüksek performanslı bir görüntü işleme algoritması uygulanacaktır.

3. Sistem Entegrasyonu ve Test: Geliştirilen donanım ve yazılım birleştirilerek, sistemin

görüntü yakalama, işleme ve görüntüleme işlevlerini beklenen performans ve stabilite ile

yerine getirip getirmediği test edilecektir.

### 2.2 Projede Gerçekçeşen İş Paketleri ve Ara Çıktıları

Projenin ara rapor dönemine kadar olan süreçte, Donanım Tasarımı fazı büyük ölçüde

tamamlanmıştır. Sistemin temel mimarisi ve bileşen entegrasyonu gerçekleştirilmiştir.

a. Literatür Taraması ve Metodolojik Hazırlık

Proje başlangıcında, benzer görüntü işleme uygulamaları üzerine bir literatür taraması

yapılmıştır. Ayrıca, projenin etkin yönetimi için GitLab (versiyon kontrolü-kod depolama-proje

görseleri-Kicad dosyaları vb.) ve Trello (görev takibi-iş akışı yönetimi-toplantı notları vb.) gibi

proje yönetim araçlarının kullanımı araştırılmış ve projenin başlangıcından itibaren aktif olarak

kullanılmaya başlanmıştır.

b. Ayrı Modül Testleri ve Karakterizasyon

Donanım entegrasyonuna geçilmeden önce, kritik modüllerin Raspberry Pi ile ayrı ayrı test

edilmesi ve karakterizasyonu gerçekleştirilmiştir:

1. ST7735 | Ekran | Testi: Ekran | modülüne | test | görüntüleri | gönderilerek SPI

haberleşmesinin işlevselliği doğrulanmıştır. Yapılan testlerde, görüntü yenileme hızının

(frame rate) kabul edilebilir bir seviyede olması için SPI hızının deneysel olarak optimize

edilmesi gerektiği gözlemlenmiştir. Yüksek çözünürlüklü görüntülerin akıcı bir şekilde

görüntülenmesi için maksimum SPI hızının (teorik 8 MHz) pratikteki üst sınırları

belirlenmiştir.

2. OV2640 | Kamera | Testi: Kamera | modülünden I²C üzerinden | konfigürasyon

ve SPI üzerinden görüntü verisi alımı test edilmiştir. Alınan görüntü verisinin (JPEG

formatında) başarılı bir şekilde Raspberry Pi'ye aktarıldığı doğrulanmıştır. Bu testler,

kamera ile Raspberry Pi arasındaki iletişim protokollerinin stabil çalıştığını göstermiştir.

c. Şematik ve PCB Tasarımı
1. Şematik Çizim: KiCad üzerinde, Raspberry Pi'nin GPIO pinlerinin OV2640 ve ST7735

modüllerine tahsis edildiği (Şekil 2.1) ve LM2596S-3.3 tabanlı SMPS devresinin pasif

bileşen değerlerinin belirlendiği detaylı devre şematiği tamamlanmıştır.

2. PCB Yerleşimi: HAT form faktörüne uygun, sinyal bütünlüğü ve termal yönetim

kurallarına uygun bir PCB yerleşimi gerçekleştirilmiştir.

d. Ara Çıktılar

Projenin ara rapor dönemine kadar elde edilen somut çıktılar şunlardır:

1. Kapsamlı Literatür Taraması Raporu.
2. GitLab ve Trello üzerinde oluşturulmuş Proje Yönetimi altyapısı.
3. ST7735 ve OV2640 modülleri için ayrı ayrı geliştirilmiş test kodları.
4. KiCad üzerinde tamamlanmış Devre Şematiği ().
5. KiCad üzerinde tamamlanmış PCB Yerleşim Dosyaları ().
6. Kameradan alınan ve Raspberry Pi'ye aktarılan görüntü örneği ().

### 2.3 Kamera Mimarisi ve Deneme Testleri


Şekil 2.1

Şekil 2.1’ de ArduCAM Mini OV2640 kamera modülünün temel mimarisi gösterilmektedir.

Sistemde, lens tarafından odaklanan görüntü OV2640 CMOS sensörüne iletilmekte ve

sensör tarafından dijitalleştirilen veri, modül içerisindeki Camera Interface birimine

aktarılmaktadır.

Görüntü verisi, ArduChip içerisinde yer alan Frame Buffer ve Memory Timing

blokları tarafından işlenerek haricî FIFO tampon belleğe yazılır. Bu yapı, sensörün piksel zamanlaması ile dış işlemcinin veri okuma hızını uyumlu hâle getirir. Sensör

konfigürasyonuna ilişkin ayarlar (pozlama, çözünürlük, renk işleme vb.), diyagramda

gösterilen I²C (SCL/SDA) hattı üzerinden yapılmaktadır.

Dış sistem ile veri iletişimi, modülün SPI Slave arayüzü üzerinden sağlanır. Bu arayüz,

FIFO’da depolanan görüntü verilerinin SPI protokolü ile yüksek hızda okunmasına olanak

tanır. Modülün genel kontrol ve durum yönetimi ise REG Module üzerinden gerçekleştirilir.

Bu bütünleşik yapı, karmaşık sensör zamanlamasını soyutlayarak görüntü verisinin Raspberry

Pitarafından kolay ve düşük işlem yüküyle alınmasını sağlar.


Şekil 3.1 | Şekil 3.2


Şekil 3.3 | Şekil 3.4

### 1. ST7735 TFT Ekran Fonksiyon Testleri

Şekil 3.[1-4]’te, ST7735 ekranın temel grafik işlevlerinin başarıyla çalıştığı görülmektedir. Bu

aşamada ekran, SPI üzerinden gönderilen piksel dizilerini doğru şekilde işleyerek renkli kareler,

çizgiler ve doğrulama amaçlı test desenlerini eksiksiz olarak göstermiştir. Bu test, ekran

sürücüsünün doğru yapılandırıldığını, SPI iletişiminin stabil olduğunu ve RGB565 formatındaki

verinin panele hatasız aktarıldığını doğrulamaktadır.


Şekil 4.1 | Şekil 4.2

Şekil 4.[1-2]’de ArduCAM OV2640 kamera modülü için yapılan testlerde, kameranın yakaladığı

görüntüler SPI arayüzü üzerinden Raspberry Pi’ye aktarılmış ve yazılım tarafından BMP

formatında kaydedilmiştir. Bu işlem, kamera ile Raspberry Pi arasındaki veri aktarımının

sorunsuz şekilde çalıştığını doğrulamak amacıyla gerçekleştirilmiştir.

### 2.4 ŞEMATİK VE PCB TASARIMI

Şekil 5.1

Şekil 5.2 | Şekil 5.3


Şekil 5.4 | Şekil 5.5

Şekil 5.[1–5]’te geliştirilen HAT kartına ait KiCad üzerinde oluşturulan devre şeması

bileşenlerini göstermektedir. Şematikte Raspberry Pi’nin 40-pin GPIO başlığı, ST7735 TFT

ekran bağlantıları, ArduCAM OV2640 kamera modülü ve LM2596S-3.3 tabanlı güç dönüştürücü

devresi ayrı alt bloklar hâlinde sunulmuştur. Raspberry Pi’den alınan SPI ve I²C hatları, kamera

ve ekran modüllerine uygun şekilde yönlendirilmiş; SPI hattı her iki modül tarafından ortak

kullanılırken çip seçme (CS) sinyalleri modüllere ayrı ayrı atanmıştır. Kamera sensörünün

yapılandırılması için gerekli I²C hattı üzerinde pull-up dirençleri eklenmiş; güç dağıtımı

bölümünde ise 5 V girişin LM2596S-3.3 devresi üzerinden kararlı 3,3 V seviyesine

dönüştürüldüğü gösterilmiştir.


Şekil 6.1


Şekil 6.2

Şekil 6.3

Şekil 6.1’de geliştirilen HAT kartına ait iki boyutlu PCB yerleşim (layout) tasarımı gösterilmektedir. Bu tasarımda Raspberry Pi’nin 40-pin GPIO başlığı, kamera ve TFT ekran konnektörleri ile LM2596S-3.3 güç dönüştürücü devresi kart üzerinde uygun konumlara yerleştirilmiştir. Yüksek hızlı SPI hatlarının mümkün olduğunca kısa ve doğru yönlendirilmesine dikkat edilmiş; güç hatlarında geniş bakır izleri tercih edilerek akım taşıma kapasitesi artırılmıştır. PCB’nin alt katmanı geniş bir toprak düzlemi olacak şekilde düzenlenmiş, böylece hem gürültü azaltma hem de sinyal bütünlüğü iyileştirilmiştir.

Şekil 6.[2-3]’de geliştirilen HAT kartının üç boyutlu PCB modelini ön ve arka yüzleriyle birlikte göstermektedir. Ön yüz görünümünde, Raspberry Pi ile uyumlu 40-pin header, kamera ve TFT

ekran konnektörleri ile LM2596S-3.3 güç dönüştürücü devresine ait SMD bileşenlerin kompakt

bir yerleşimle konumlandırıldığı görülmektedir. Arka yüz görünümünde ise geniş bir toprak

düzlemi (GND plane) tercih edilerek sinyal bütünlüğünün artırılması ve yüksek hızlı SPI

hatlarında gürültünün azaltılması hedeflenmiştir. Arka katmanın büyük oranda boş bırakılması,

hem ısı dağılımını iyileştirmekte hem de üst yüzdeki bileşenlerin daha stabil çalışmasına katkı

sağlamaktadır.

KAYNAKLAR

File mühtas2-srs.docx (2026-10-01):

KOCAELİ ÜNİVERSİTESİ

MÜHENDİSLİK FAKÜLTESİ


FPGA-BASED MULTI-CAMERA GIMBAL VISION SYSTEM PROJESİ

MÜHTAS-2

2025-2026 DÖNEM PROJESİ

SİSTEM GEREKSİNİMLERİ RAPORU

Öğrencinin Adı Soyadı:

Sena Sümeyye DURARSLAN

220208041

Bölümü: Elektronik ve Haberleşme Mühendisliği

Danışman: Doç. Dr. Anıl ÇELEBİ

KOCAELİ, 2026

İÇİNDEKİLER:

1. Giriş
2. Fonksiyonel Gereksinimler
3. Donanım Gereksinimleri
4. Yazılım Gereksinimleri
5. Arayüz Gereksinimleri (I/O)

1.Giriş

Bu projede Pcam kamera modülünden elde edilen görüntüler, ZedBoard geliştirme kartı üzerinde yer alan FPGA ve ARM işlemci birimlerinin birlikte kullanılmasıyla işlenecek ve Ethernet üzerinden bir bilgisayara aktarılacaktır. PL kısmı görüntü verisinin alınması ve veri akışının yönetilmesinde görev alırken, PS kısmı veri aktarımı ve sistem kontrolünü gerçekleştirecektir. Bilgisayar tarafında ise alınan görüntüler OpenCV kütüphanesi kullanılarak işlenecek ve iki farklı kamera görüntüsü birleştirilerek panoramik bir görüntü oluşturulacaktır.

2. Fonksiyonel Gereksinimler

Bir sistemin ne yapması gerektiğini tanımlayan temel gereksinimler. Sistemin kullanıcıya veya diğer sistemlere sağlaması gereken davranışları, görevleri ve işlevleri açıklar.

ID | Kullanılma Nedeni/İşlevi | Gösterim
FR-01 Sistem başlatma | Zynq tabanlı sistem açıldığında FPGA tasarımı yüklenmeli ve bare-metal uygulama otomatik olarak başlatılacaktır.
FR-02 Kamera başlatma | Sistem, iki adet Pcam 5C kamera modülünü I2C üzerinden konfigüre edebilecektir..
FR-03 Görüntü yakalama | Sistem, her iki kameradan görüntü alacaktır.
FR-04 Paralel kamera işleme | İki kameradan gelen görüntü akışları eş zamanlı olarak işlenecektir.
FR-05 Veri aktarımı (PL to DDR) | Kamera verisi PL tarafından alınarak DMA kullanımı ile DDR belleğe aktarılacaktır.
FR-06 Veri aktarımı (DDR → PS) | Bellekte tutulan görüntü verisi PS tarafından erişilebilir olacaktır
FR-07 Ethernet veri iletimi | Görüntü verisi PS üzerinden UDP protokolü kullanılarak bilgisayara gönderilecektir.
FR-08 PC tarafı veri alma | Bilgisayar tarafındaki yazılım gelen görüntü verisini alacak ve decode edecektir..
FR-09 Görüntü ön işleme | Kamera görüntüleri lens distorsiyonuna karşı düzeltilecektir. (undistortion).
FR-10 Görüntü eşleştirme | İki görüntü arasında ortak özellik noktaları belirlenecektir (feature matching).
FR-11 Panorama oluşturma | OpenCV kullanılarak iki görüntü hizalanacak ve birleştirilecektir.
FR-12 Görüntü gösterimi | Oluşturulan panoramik görüntü kullanıcıya gerçek zamanlıya yakın şekilde sunulacaktır.

3.Donanım Gereksinimleri

Bu bölümde, sistemin fiziksel olarak gerçekleştirilebilmesi için gerekli olan donanım bileşenleri tanımlanmaktadır.

ID | Bileşen/Modül | Kullanılma Nedeni/İşlevi | Gösterim
HW-01 | ZEDBOARD Advanced Image Processing Kit | Sisteminin ana işlem birimidir. FPGA (PL) ve ARM işlemci (PS) yapısını içerir. Kamera verisinin alınması, işlenmesi ve Ethernet üzerinden aktarılması işlemlerini gerçekleştirir.
HW-02 | FMC Adaptör | Pcam kamera modüllerinin ZedBoard üzerine bağlanmasını sağlar. MIPI CSI-2 veri hattını destekler. | Kamera modülü fiziksel olarak bağlanacaktır.
HW-03 | Pcam 5C *2 | Görüntü verisini üreten sensördür (OV5640). Sistem iki adet kamera ile çalışacaktır. | Her iki kameradan ayrı görüntü alınacaktır.
HW-04 | Ethernet Kablosu | Görüntü verisinin bilgisayara aktarılması için kullanılır. | PC ile bağlantı kurularak veri paketleri alınacaktır.
HW-05 | Kamera Mount | Kameraların sabit açıyla konumlandırılmasını sağlar. | Kameraların sabit konumda kalması ve görüntüde bozulma olmaması ile doğrulanacaktır.
HW-06 | DDR3 Bellek | Kamera verilerinin geçici olarak saklanmasını sağlar (frame buffer).
HW-07 | Pc Ekranı | Ethernet üzerinden gelen görüntü verisinin alınması, işlenmesi ve panoramik görüntü oluşturulması için kullanılacaktır. | Gelen görüntü işlendikten sonra ekranda gösterilecektir.

4.Yazılım Gereksinimleri

Bu bölümde sistemin çalışmasını sağlayan yazılım bileşenleri ve bu bileşenlerin görevleri tanımlanmaktadır. Sistem, Zynq platformu üzerinde bare-metal (işletim sistemi olmadan) çalışacak şekilde tasarlanacaktır.

ID | Yazılım | Kullanılma Nedeni/İşlevi
SW-01 | Vivado | PL tarafında kamera veri yolu, AXI arabirimleri ve DMA gibi donanımsal bileşenlerin tasarımı ve sentezlenmesi için kullanılacaktır.
SW-02 | Vitis / SDK | PS üzerinde çalışacak yazılım uygulamasının geliştirilmesi için kullanılacaktır. Kamera kontrolü, veri aktarımı ve sistem yönetimi bu katmanda gerçekleştirilecektir.
SW-03 | Python | Bilgisayar tarafında görüntü verisini almak, işlemek ve görselleştirmek için kullanılacaktır.
SW-04 | OpenCV | İki kamera görüntüsünün işlenmesi ve panoramik görüntü oluşturulması için kullanılacaktır. Görüntü hizalama, dönüşüm ve birleştirme işlemleri bu kütüphane ile gerçekleştirilecektir.
SW-05 | lwIP Tabanlı Haberleşme | Ethernet üzerinden bilgisayara veri aktarımı için UDP ağ protokolü kullanılacaktır. Bu yapı, görüntü verisinin düşük gecikme ile iletilmesini sağlayacaktır.

5.Arayüz Gereksinimleri

Bu bölümde sistem bileşenleri arasındaki veri iletişimini sağlayan arayüzler ve kullanılan protokoller tanımlanmaktadır.

ID | Arayüz | Protokol | Kullanılma Nedeni/İşlevi
IR-01 | Kamera Veri | MIPI CSI-2 | Kameradan FPGA’ya yüksek hızlı görüntü aktarımı sağlayacaktır.
IR-02 | Kamera Kontrol | I2C | Kamera sensör konfigürasyonu için kullanılacaktır.
IR-03 | Bellek Arayüzü | AXI | FPGA ile DDR bellek arasında veri transferini sağlayacaktır.
IR-04 | DMA Arayüzü | AXI DMA | Kamera verisinin işlemciye yük bindirmeden belleğe aktarılmasını sağlayacaktır.
IR-05 | Ethernet | UDP | Görüntü verisinin bilgisayara iletilmesini sağlayacaktır.
IR-06 | PC Arayüzü | Socket | Bilgisayar tarafında veri alma ve işleme işlemleri için kullanılacaktır.


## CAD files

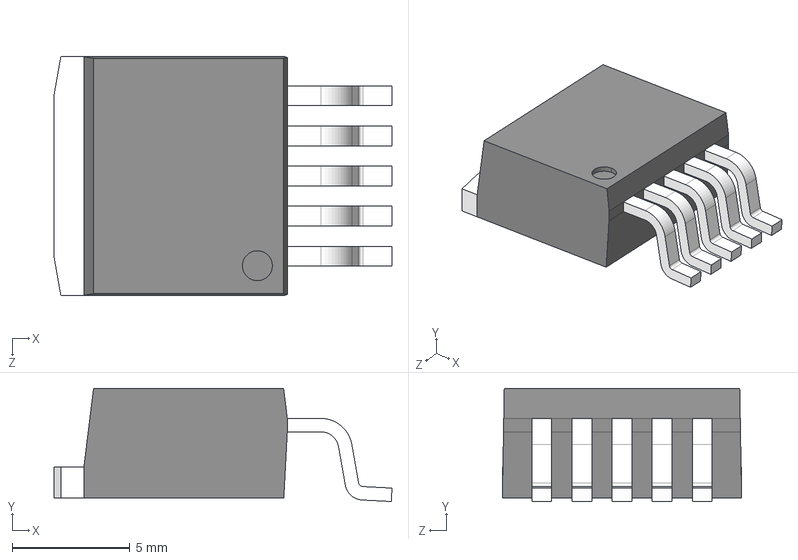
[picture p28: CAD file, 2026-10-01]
KiCad/LM2596S-3.3.step
14.4 x 4.80 x 10.2 mm

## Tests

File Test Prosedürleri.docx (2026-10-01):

Bu doküman, OV7670 kamera ve ST7735 ekranını Raspberry Pi 5 üzerinde çalıştırmaya yönelik proje için, sistem tasarımı öncesi ve sonrası uygulanacak test prosedürlerini tanımlar. Amaç, PCB tasarımına geçmeden önce tüm donanım ve yazılım bileşenlerinin işlevsel olarak doğrulanmasıdır.

ÖN TEST DÖNEMİ

1.Aşama — Donanım ve Bağımsız Bileşen Testleri

Amaç: her bileşeni ayrı ayrı test edip çalıştığından emin olmak.

A. Kamera Testi

B. Ekran Testi

Adım | Amaç | Test / Gözlenen Sonuç | Gerekli araçlar
1. GPIO-SPI doğrulaması | Pi’nin SPI hattı sağlıklı mı? | ST7735 ekranında framerate_test örneği düzgün görüntü verir. | Display_Lib_RPI örnek kodu
2. SPI buffer artırma | Büyük veri bloklarını aktarabilir mi? | cat /sys/module/spidev/parameters/bufsiz → 65536 | Terminal
3. ST7735 performans testi | Ekran donanımı sorunsuz mu? | Renk geçişleri, yazı, şekiller düzgün görünür. | Mevcut test
4. I²C (SCCB) doğrulaması | OV7670 register’larına erişebiliyor musun? | . | i2c-tools veya C test kodu
5. Kamera clock ve besleme | XCLK ve güç hatları doğru mu?
6. Color-bar testi | Görüntü akışı var mı? | Color-bar patern PCLK/HREF/VSYNC sinyallerinde gözlenir. | Logic analyzer
7. GPIO kesme yakalama (simülasyon) | Pi’nin IRQ ile satır/piksel tetiklemesi güvenilir mi? | PCLK’i 100 kHz kare dalga ile besle → IRQ callback sayısı tutarlı | Python veya C IRQ denemesi
8. Kameradan tek kare yakalama | Donanımsal kesmeyle veri alımı çalışıyor mu? | Color-bar verisinden 160×120 buffer oluşur. | C++ libgpiod denemesi
9. Tek kareyi ekrana basma | Ekran veri yolunun uyumu | Color-bar görüntüsü ST7735’te görünür. | C/C++
10. Gerçek görüntü testi | Lensli modda görüntü doğruluğu | Renkler doğru, 1 fps civarında yenileniyor. | Işık ortamı

2.Aşama — Görüntü Yakalama + Ekrana Yazdırma Entegrasyonu

PROJE GELİŞTİRME

Faz 1 — Mimari & Planlama

Amaç: Kart topolojisini ve veri akışını netleştir.

- Pin eşlemelerini belirle (OV7670 D0-D7, PCLK, HREF, VSYNC, SCCB; ST7735 SPI; güç).
- Blok şema çiz (kamera, Pi, ekran, regülatör, header).
- Donanım gereksinim belgesi (voltajlar, pin yönleri, akım tahminleri).

Faz 2 — Yazılım Prototipi (Breadboard üzerinde)

Amaç: PCB’siz ortamda tam veri yolunu 1 fps’te kanıtla.

Faz 3 — PCB Tasarımı (donanım ekibi)

Amaç: Breadboard’daki hatayı ortadan kaldıran, HAT uyumlu PCB.

- Pi 5 40-pin header’ı referans al
- Kameranın D0–D7 + sync hatlarını düzgün uzunlukta paralel route et
- XCLK kaynağını (osc. veya Pi clock) netleştir
- Güç hattına LDO (5V→3.3V 300 mA) ekle
- Decoupling C ve test-point’ler (PCLK, VSYNC, 3V3, GND)
- Gerber v1 üret, DRC temizle
- 3D model & pinout diyagramını docs/ içine koy

Faz 4 — Yazılım Revizyonu (PCB üstünde)

Amaç: Donanım sabitken kodu optimize et.

Faz 5 — Test & Kalibrasyon

Amaç: Kartın üretim sonrası her birim için kalite testi.

- Güç hattı test (3.3 V sabit mi?)
- Kamera ID testi (COM7 okuma)
- Color-bar testi (otonom “PASS/FAIL”)
- Gerçek lens testi (1 fps)
- Termal test (ısınma)
- Ekran renk doğrulama (gri seviye patern)

Faz 6 — Dokümantasyon & Paketleme

Amaç: Projeyi üretim-veya paylaşım seviyesine getir.

- README.md → kurulum, bağlantı, derleme
- docs/test → test adımları ve referans sonuçlar
- schematic.pdf, pcb_layout.pdf, pin_map.xlsx
- tüm kod
- Gerber, fotoğraflar

Tüm test adımları tamamlandığında sistem, düşük fps canlı görüntü aktarımını donanımsal kesmeler üzerinden gerçekleştirebilir duruma gelecektir.

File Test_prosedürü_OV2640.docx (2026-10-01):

KOCAELİ ÜNİVERSİTESİ

MÜHENDİSLİK FAKÜLTESİ


RASOBERRY Pİ GÖRÜNTÜ İŞLEME HAT PROJESİ

2025-2026 DÖNEM PROJESİ

TEST PROSEDÜR RAPORU

Öğrencinin Adı Soyadı:

Sena Sümeyye DURARSLAN

Bölümü: Elektronik ve Haberleşme Mühendisliği

Danışman: Yrd. Doç. Dr. Anıl ÇELEBİ

KOCAELİ, 2025

İÇİNDEKİLER:

1.Dökümanın Amacı

2.Test Ortamı ve Ön Koşullar

2.1 Donanım Bileşenleri

2.2 Yazılım Bileşenleri

2.3 Ön Koşullar

3. Test Mimarisi ve Bağlantı Yapısı

4. Test Prosedürleri ve Adımları

4.1 Bölüm 1

4.2 Bölüm 2

1. Dokümanın Amacı

Bu doküman, Raspberry Pi 4 , ArduCAM-M-2MP (OV2640) kamera modülü ve ST7735 TFT ekranın entegrasyonunu doğrulamak için izlenen test adımlarını ve prosedürlerini tanımlar. Amaç, donanım arayüzlerinin (I2C, SPI) doğru yapılandırıldığını, veri akışının sağlandığını ve sistemin canlı görüntü akışı hedefine ulaştığını sistematik olarak kanıtlamaktır.

2. Test Ortamı ve Ön Koşullar

2.1. Donanım Bileşenleri

- Ana İşlemci: Raspberry Pi 4 Model B
- Görüntüleme (Giriş): ArduCAM-2MP (OV2640 Sensörlü)
- Görüntüleme (Çıkış): ST7735 1.8" SPI TFT Ekran (160x128 Çözünürlük)

2.2. Yazılım Bileşenleri

- İşletim Sistemi: Raspberry Pi OS
- Dil: C/C++
- Çekirdek Arayüzleri: spidev (SPI Sürücüsü), i2c-dev (I2C Sürücüsü)
- Kütüphaneler: libi2c-dev, picojpeg(Görüntü işleme), pigpio (GPIO Kontrolü), Display_Lib_RPI(TFT ekrana basma)(lgpio destekli)
- Kamera sürücü katmanı: spi_linux.c, i2c_linux.c, arduchip.c, ov2640.c
- JPEG decode: picojpeg.c + jpeg_to_rgb565.c
- TFT sürücü: Display_Lib_RPI (ST7735) + lgpio
- Makefile: test hedefleri: -make help
- test_hal
- test_arduchip
- capture_app
- decode_test
- capture_screen

2.3. Ön Koşullar

- Tüm donanım bağlantıları mimari plana göre yapılmıştır.
- Raspberry Pi OS üzerinde sudo raspi-config aracı ile I2C ve SPI arayüzleri "Enabled" (Etkin) durumdadır.
- Gerekli tüm kütüphaneleri sisteme kurulmuştur.
- Test edilecek programlar derlenmiş ve çalıştırılabilir bir dosya oluşturulmuştur.(make clean ile temizlenerek yeniden derlenecektir.)

3. Test Mimarisi ve Bağlantı Yapısı

Testler, paylaşımlı tek bir SPI veri yolu (SPI0) mimarisine göre yapılandırılmıştır.

- I2C Yolu (i2c-1): RPi (SDA, SCL) ArduCAM (SDA, SCL) (Sensör yapılandırması için)
- SPI Yolu (spi0):
  - Paylaşılan Pinler: RPi (MISO, MOSI, SCLK) Hem ArduCAM hem ST7735'in ilgili pinlerine.(Blok diyagramında detaylı gösterilmiştir)
  - Aygıt Seçimi (CS):
    - RPi (CE0 / GPIO 8) ArduCAM CS (Linux: /dev/spidev0.0)
    - RPi (CE1 / GPIO 7) ST7735 CS (Linux: /dev/spidev0.1)
- Kontrol Pinleri (GPIO):
  - RPi (GPIO 24) ST7735 D/C (Data/Command)
  - RPi (GPIO 25) ST7735 RST (Reset)

4. Test Prosedürleri ve Adımları

Testler, donanım arayüzünden tam entegrasyona doğru modüler bir yaklaşımla gerçekleştirilmiştir. Raspberry Pi termimaline make help komutu girildiğinde test aşamaları görülecektir.

Bölüm 1: Donanım Arayüzü Doğrulama Testleri

Test ID | Test Adı | Amaç | Komut | Beklenen Sonuç | Durum | Gereksiniim
TP-1.01 | I2C Arayüz Algılama | Raspberry Pi'nin I2C veri yolu üzerinden OV2640 sensörünü algılayabildiğini doğrulamak. | sudo i2cdetect -y 1 | Çıktı tablosunda 0x30 (7-bit I2C adresi) değerinin görünmesi | BAŞARILI / BAŞARISIZ | IR-01,
TP-1.02 | SPI Arayüzü Algılama | Linux çekirdeğinin SPI0 veriyolunu ve iki Chip Select (CS) hattını tanıdığını doğrulamak. | ls -l /dev/spi* | Terminalde /dev/spidev0.0 ve /dev/spidev0.1 aygıt dosyalarının görünmesi. | BAŞARILI / BAŞARISIZ | IR-02, IR-03
TP-1.03 | İşletim Sistemi Doğrulama | Raspberry Pi OS Bookworm versiyonunu doğrulamak | hostnamectl | ….. Debian 12 (bookworm) Linux 6.12.47… | BAŞARILI / BAŞARISIZ | SW-01
TP-1.04 | Yazılım mimarisi | Yazılım mimarisinin belirtilen modüllere ayrılmış olduğu doğrulanacaktir. | ls (tüm dosyaları gösterir) ls *.c *.h *.cpp [Mm]akefile (sadece bu türdeki uzantıları gösterir) | spi_linux.c/h (SPI driver) i2c_linux.c/h (I2C driver) arduchip.c/h (Kamera kontrol) ov2640.c/h (Sensor config) picojpeg.c/h (JPEG decode) jpeg_to_rgb565.c/h (Format convert) decode_test ov2640_regs.c/h Display_Lib_RPI (TFT driver) capture_to_file.c/h (jpeg kaydetme) capture_screen (Ana uygulama) test_xxx | BAŞARILI / BAŞARISIZ | SW-03

Bölüm 2: Aygıt Başlatma ve İletişim Testleri (Makefile dosyası kullanılarak)

1.Terminal ekranında cd project komutu ile proje dosyasına gidilecek

2.Proje dosyası konum olarak açıldıktan sonra make help komutu ile gerekli testlerin komutları görüntülenecektir.

Test ID | Test Adı | Amaç | Komut | Beklenen Sonuç | Durum | Gereksinim
TP-2.01 | test_hal | I2C ve SPI donanım arayüzlerinin, uygulama katmanından HAL aracılığıyla erişilebilir ve işlevsel olduğu birlikte doğrulanacaktır. | make test_hal (derleme) sudo ./test_hal (çalıştırma) | SPI camera open OK (/dev/spidev0.0) SPI TFT open OK (/dev/spidev0.1) I2C camera open OK (/dev/i2c-1, addr=0x30) SPI camera transfer OK (rx=0x00) | BAŞARILI / BAŞARISIZ | IR-01 IR-02 IR-03
TP-2.02 | test_arduchip | SPI (/dev/spidev0.0) üzerinden ArduCAM modülünün kontrol birimi (ArduChip) ile iletişim kurulabildiği doğrulanacaktır. | make test_arduchip (derleme) sudo ./test_arduchip(çalıştırma) | Writing 0x55 to ARDUCHIP_TEST1 (0x00)... Read back: 0x55 OK: SPI interface / ArduChip TEST1 PASSED. ArduChip version register = 0x40 (veya 0x4X) FIFO length = 0 bytes | BAŞARILI / BAŞARISIZ | IR-01 IR-02
TP-2.03 | capture_app | Kamera FIFO belleğinden geçerli bir JPEG görüntü verisinin elde edilebildiğini ve .jpeg uzantılı dosya olarak kaydedilebildiği doğrulanacaktır. | make capture_app (derleme) sudo ./capture_app (çalıştırma) | frame.jpg project dosyasına .jpg uzantılı dosya kaydedilcektir. | BAŞARILI / BAŞARISIZ | FR-02 FR-04
TP-2.04 | decode_test | Kamera tarafından elde edilen JPEG görüntünsünün doğru şekilde RGB565 formatına dönüştürüldüğü doğrulanacaktır. | make decode_test (derleme) sudo ./decode_test (çalıştırma) | project dosyasında frame.rgb565 dosyası oluşacaktır. terminalde ls -l frame.rgb565 komutu ile doğrulanacaktır. | BAŞARILI / BAŞARISIZ | FR-03
TP-2.05 | capture_screen | Kamera tarafından çekilen görüntünün TFT ekranda gösterilmesi doğrulanacaktır. | make capture_screen (derleme) sudo ./capture_screen (çalıştırma) | Tft başlatılıyor… Jpeg length: xx bytes TFT görüntü basar Not: error99 hatası almak problem değildir. | BAŞARILI / BAŞARISIZ | FR-05 /FR-06 HW-10 / HW-11 HW-14 SW-02 / SW-03 SW-04 / SW-05 IR-01 / IR-02 IR-03 / IR-04
TP-2.06 | capture_screen_10 | Sistem, entegrasyonun kararlılığını ölçmek amacıyla, ana uygulama art arda 10 kez çalıştırılarak test edilecektir. | for i in $(seq 1 10); do sudo ./capture_screen; done | Ekranda görüntü gelirken bir takılma olmaması ve terminalde baaşrısız hatası alınmaması ile doğrulanacaktır. | BAŞARILI / BAŞARISIZ | FR-07
TP-3.01 | Ana İşlem Birimi Doğrulama | Raspberry Pi 4B’nin sistemin ana işlem birimi olarak çalıştığını ve Hat tasarımına uyumlu çalıştığını doğrulamak | Raspberry Pi’ye güç verildiğinde SD karta kurulumu yapılan arayüzün TigerVNC aracılığıyla bilgisayarda açılması ve konnektörler aracılığıyla bağlı bileşenlerin başlatılmasıyla doğrulanacaktır. | Tiger VNC ile bağlantı kurulduğunda arayüz açılacak ve Hat üzerindeki bileşenlere güç gidecektir. | BAŞARILI / BAŞARISIZ | FR-01 HW-01 HW-02 HW-09 HW-14
TP-3.02 | Voltaj Regülatör (LM2596) | Kamera ve Ekran için gereken güç dönüşümünün yapılarak modüllerin ve bağlı bileşenlerin çalışmasıyla doğrulanacaktır. | Multimetrenin pozitif probu LM2596'nın giriş pinine (veya giriş kondansatörüne), negatif probu ise GND'ye bağlanacaktır. | Regülatör girişinde 4.75V < Vin < 5.25V ve regülatör çıkışında 3.20V < Vout < 3.40V gözlemlenecektir | BAŞARILI / BAŞARISIZ | HW-03 HW-04 HW-05 HW-06 HW-07 FR-08 IR-05 IR-06
TP-3.03 | Led Gösterge Durumu | Regülatör girişinde ve çıkışında güç olduğunda görsel olarak doğrulanacaktır. | Kart Raspberry Pi’ye konnectörler ile bağlanacaktır. | Regülatör girişinde yeşil led ve çkışında kırmızı led yanacaktır. | BAŞARILI / BAŞARISIZ | HW-08 HW-12 HW-13

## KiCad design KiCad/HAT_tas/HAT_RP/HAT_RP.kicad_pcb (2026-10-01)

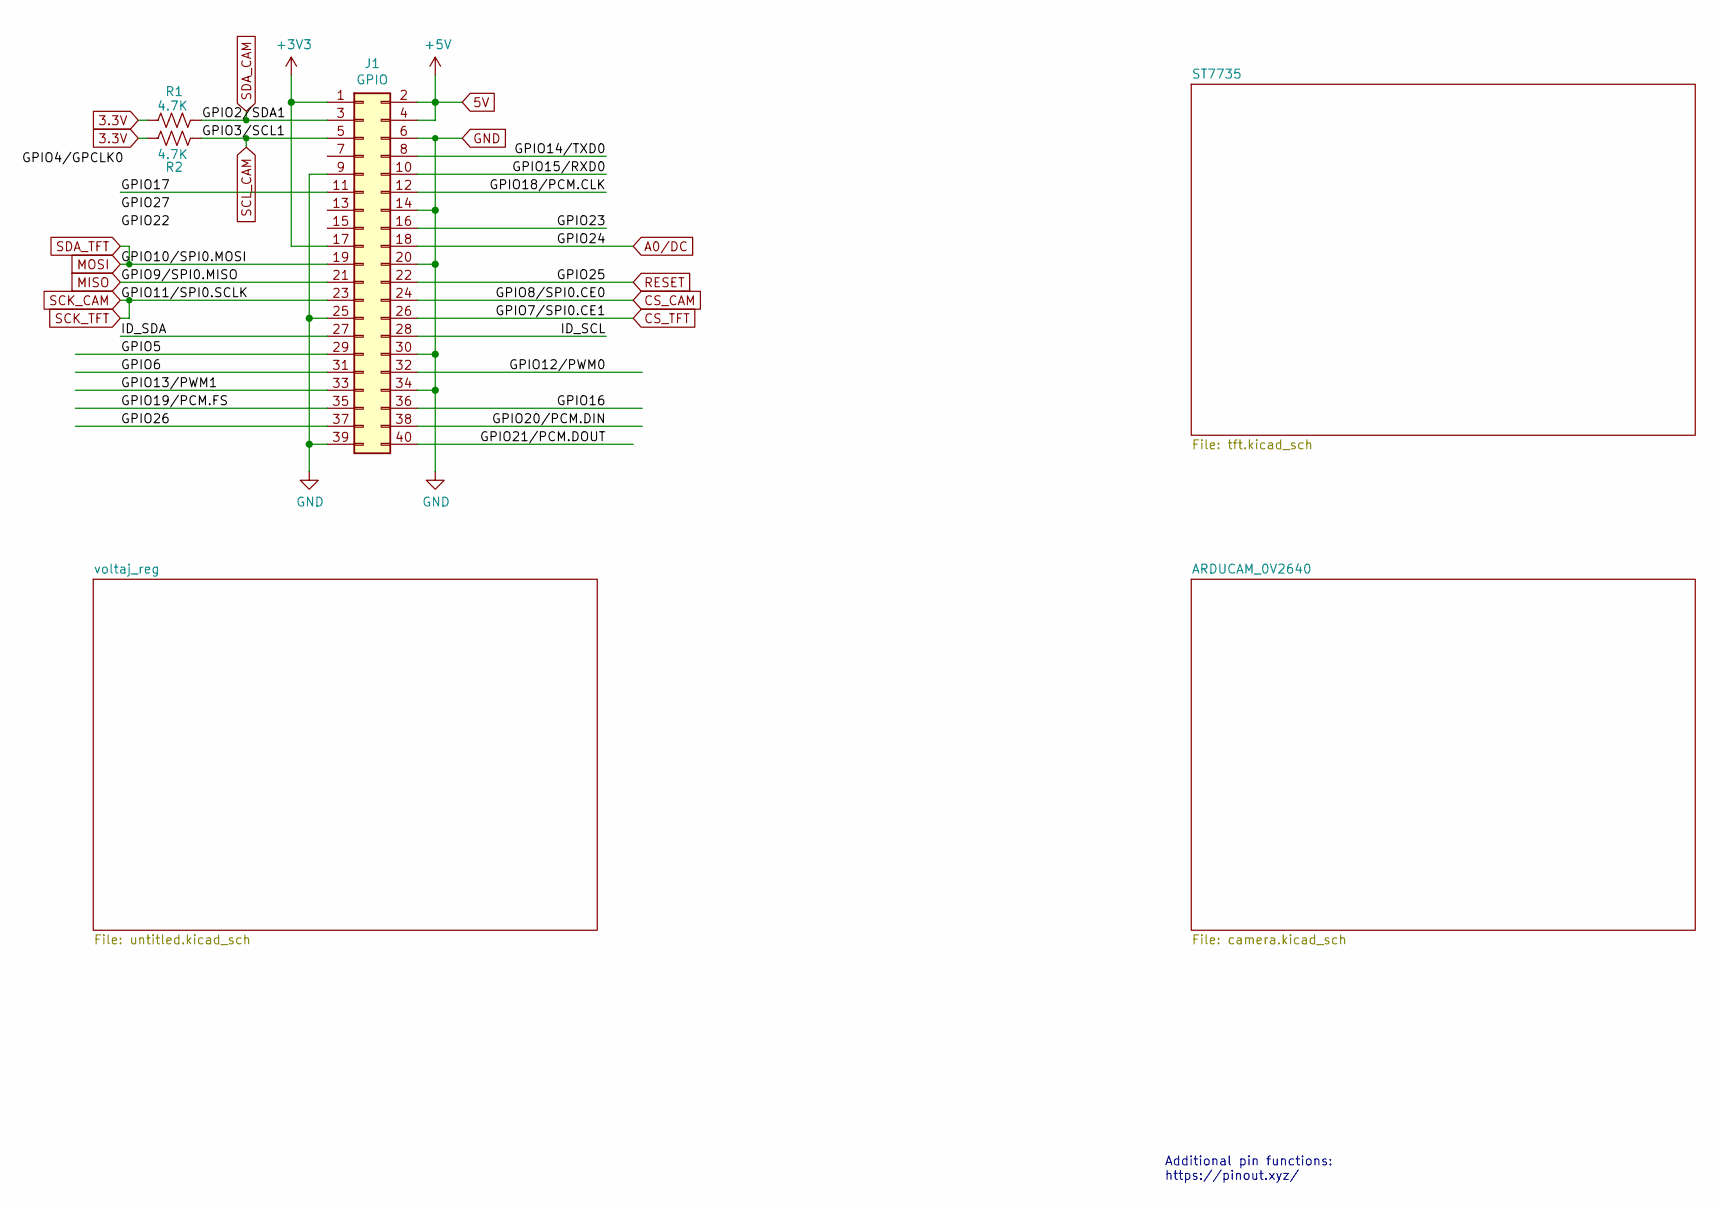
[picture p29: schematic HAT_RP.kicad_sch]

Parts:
J1: GPIO; PinSocket_2x20_P2.54mm_Vertical
R1, R2: 4.7K; R_0805_2012Metric

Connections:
3.3V: R1.1, R2.1; also elsewhere on the board
5V: J1.2, J1.4; also elsewhere on the board
+3V3: J1.1, J1.17
/GPIO5: J1.29
/GPIO6: J1.31
/GPIO12/PWM0: J1.32
/GPIO13/PWM1: J1.33
/GPIO14/TXD0: J1.8
/GPIO15/RXD0: J1.10
/GPIO16: J1.36
/GPIO17: J1.11
/GPIO18/PCM.CLK: J1.12
/GPIO19/PCM.FS: J1.35
/GPIO20/PCM.DIN: J1.38
/GPIO21/PCM.DOUT: J1.40
/GPIO23: J1.16
/GPIO26: J1.37
/ID_SCL: J1.28
/ID_SDA: J1.27
A0/DC: J1.18; also elsewhere on the board
CS_CAM: J1.24; also elsewhere on the board
CS_TFT: J1.26; also elsewhere on the board
GND: J1.6, J1.9, J1.14, J1.20, J1.25, J1.30, J1.34, J1.39; also elsewhere on the board
MISO: J1.21; also elsewhere on the board
MOSI: J1.19; also elsewhere on the board
RESET: J1.22; also elsewhere on the board
SCK_CAM: J1.23; also elsewhere on the board
SCL_CAM: J1.5, R2.2; also elsewhere on the board
SDA_CAM: J1.3, R1.2; also elsewhere on the board

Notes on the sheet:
Additional pin functions: https://pinout.xyz/

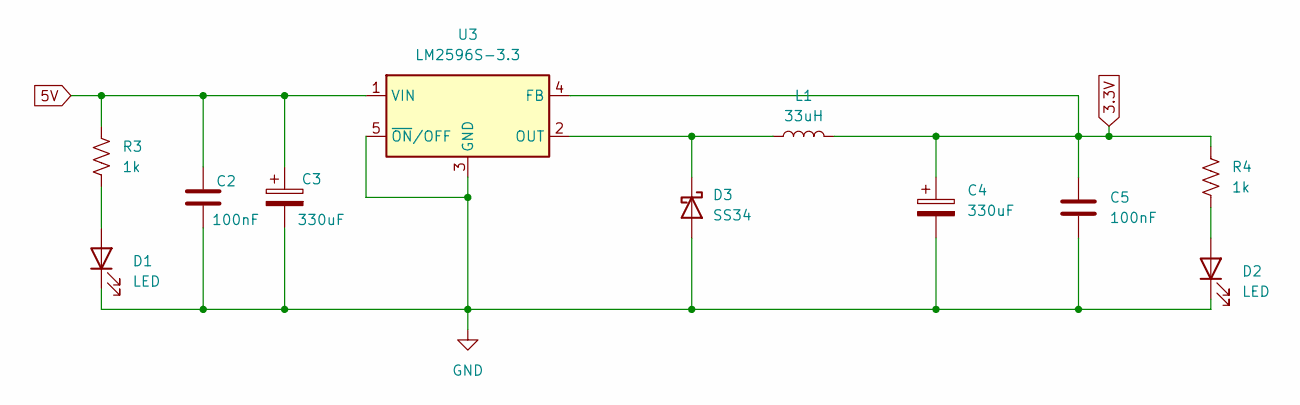
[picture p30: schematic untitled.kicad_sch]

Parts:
C2, C5: 100nF; C_0805_2012Metric
C3, C4: 330uF; CP_Elec_8x10
D1, D2: LED; LED_0805_2012Metric
D3: SS34; D_SMA
L1: 33uH; L_12x12mm_H8mm
R3, R4: 1k; R_0805_2012Metric
U3: LM2596S-3.3; TO-263-4

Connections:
3.3V: C4.1, C5.1, L1.2, R4.1, U3.4 (FB); also elsewhere on the board
5V: C2.1, C3.1, R3.1, U3.1 (VIN); also elsewhere on the board
GND: C2.2, C3.2, C4.2, C5.2, D1.1 (K), D2.1 (K), D3.2 (A), U3.3 (GND), U3.5 (~ON/OFF); also elsewhere on the board
unnamed: D1.2 (A), R3.2
unnamed: D2.2 (A), R4.2
unnamed: D3.1 (K), L1.1, U3.2 (OUT)

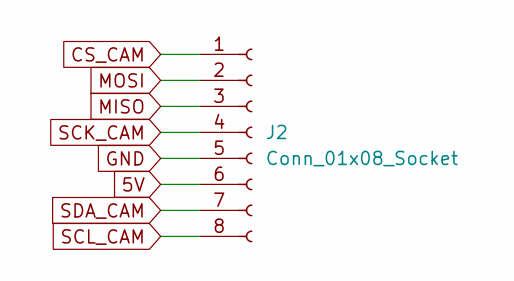
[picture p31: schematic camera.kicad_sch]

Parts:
J2: Conn_01x08_Socket; PinSocket_1x08_P2.54mm_Vertical

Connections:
5V: J2.6; also elsewhere on the board
CS_CAM: J2.1; also elsewhere on the board
GND: J2.5; also elsewhere on the board
MISO: J2.3; also elsewhere on the board
MOSI: J2.2; also elsewhere on the board
SCK_CAM: J2.4; also elsewhere on the board
SCL_CAM: J2.8; also elsewhere on the board
SDA_CAM: J2.7; also elsewhere on the board

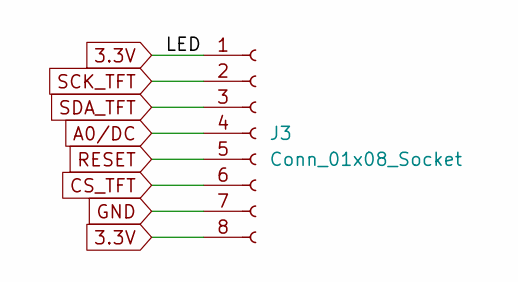
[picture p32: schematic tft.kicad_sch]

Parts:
J3: Conn_01x08_Socket; PinSocket_1x08_P2.54mm_Vertical

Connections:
3.3V: J3.1, J3.8; also elsewhere on the board
A0/DC: J3.4; also elsewhere on the board
CS_TFT: J3.6; also elsewhere on the board
GND: J3.7; also elsewhere on the board
MOSI: J3.3; also elsewhere on the board
RESET: J3.5; also elsewhere on the board
SCK_CAM: J3.2; also elsewhere on the board

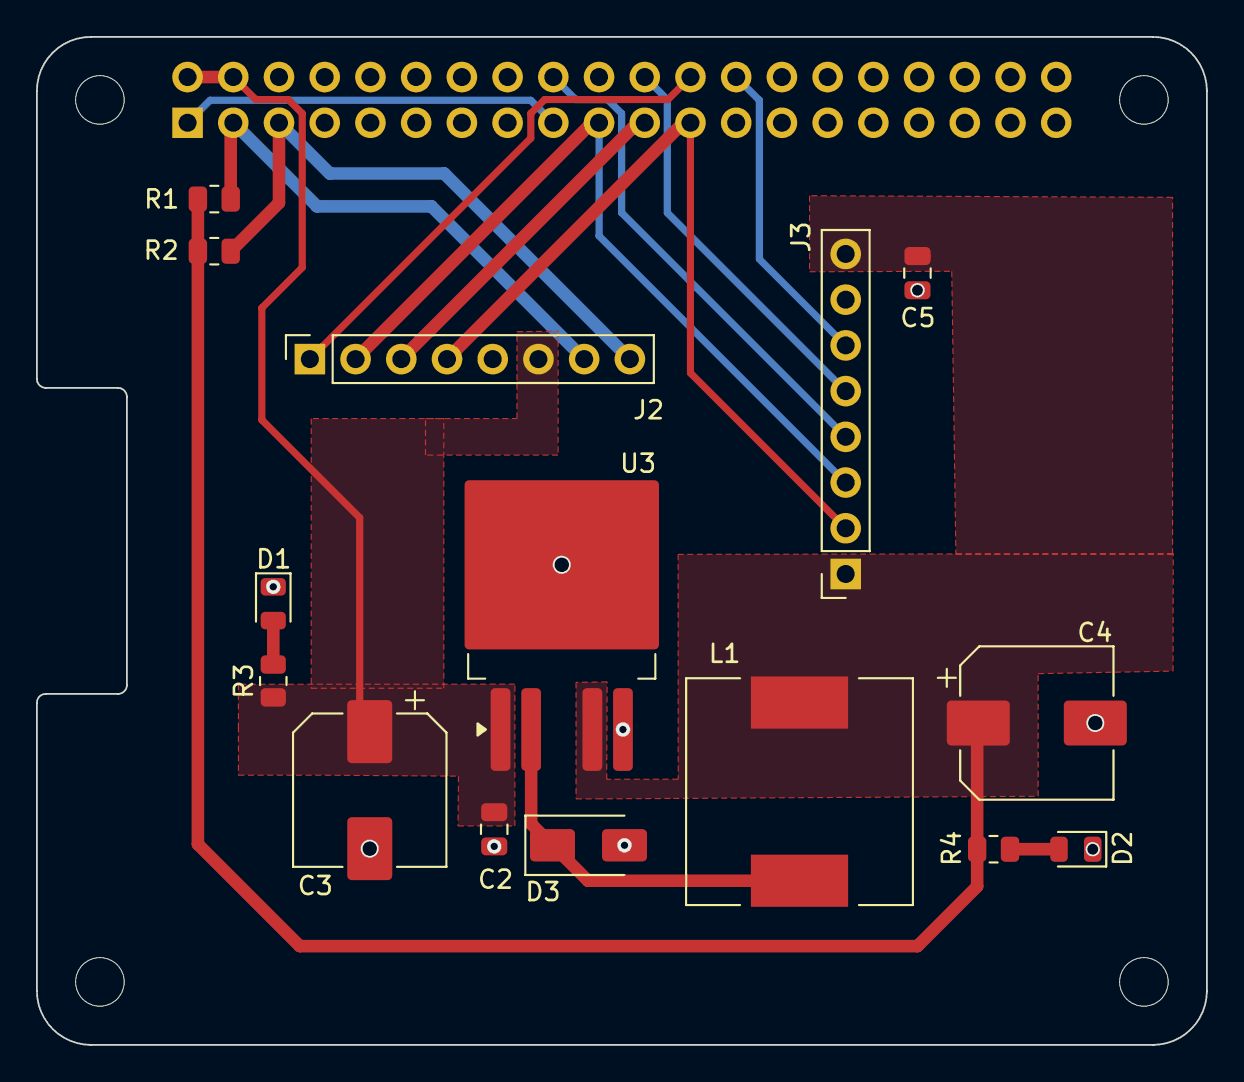
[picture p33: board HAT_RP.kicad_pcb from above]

Board: 2 copper layers, 65.0 x 56.0 mm, 20 parts (1 on the bottom side), 16 nets.

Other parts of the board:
MH1, MH2, MH3, MH4: MountingHole_2.7mm_M2.5

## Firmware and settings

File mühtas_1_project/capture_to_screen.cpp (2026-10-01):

#include <iostream>
#include <vector>
#include <cstdint>
#include <cstdio>
#include <cstdlib>
#include <cstring>
#include <unistd.h>

// C k�t�phanesi i�in extern olu�turarak c++ kodunda kulland�k
extern "C" {
#include "spi_linux.h"
#include "i2c_linux.h"
#include "arduchip.h"
#include "ov2640.h"
#include "jpeg_to_rgb565.h"
}

// TFT k�t�hanesi
#include <ST7735_TFT_LCD_RDL.hpp>

// ArduChip Register Maskeleri
#define FIFO_CLEAR_MASK      0x01
#define FIFO_RDPTR_RST_MASK  0x10
#define FIFO_WRPTR_RST_MASK  0x20

ST7735_TFT myTFT;

int8_t RST_TFT      = 25;
int8_t DC_TFT       = 24;
int   GPIO_CHIP_DEV = 0;

uint8_t  OFFSET_COL = 0;
uint8_t  OFFSET_ROW = 0;
uint16_t TFT_WIDTH  = 128;
uint16_t TFT_HEIGHT = 160;

int SPI_DEV    = 0;
int SPI_CHANNEL= 1; 
int SPI_SPEED  = 8000000;
int SPI_FLAGS  = 0;

//================== Prototipler ==================
static uint8_t SetupDisplay();
static void    ShowErrorOnTFT(const char* msg);
static bool    CaptureJPEG(std::vector<uint8_t>& jpeg_buf, uint32_t& jpeg_len);
static bool    DecodeAndShow(const uint8_t* jpeg_data, uint32_t jpeg_len);

//================== Main =========================
int main()
{
    // 1. Ekranı hazırla
    if (SetupDisplay() != 0) {
        std::cerr << "TFT Kurulumu basarisiz!\n";
        return 1;
    }

    std::vector<uint8_t> jpeg_data;
    uint32_t jpeg_len = 0;

    // 2. Kameradan taze görüntü yakala
    std::cout << "Kameradan goruntu aliniyor...\n";
    if (!CaptureJPEG(jpeg_data, jpeg_len)) {
        std::cerr << "Kamera yakalama hatasi!\n";
        ShowErrorOnTFT("CAPTURE FAIL");
        myTFT.TFTPowerDown();
        return 1;
    }
    
        // --- İSTEDİĞİNİZ SATIR BURADA ---
    std::cout << "jpeg length : " << jpeg_len << " bytes" << std::endl;

    // 3. Çöz ve ekrana bas
    if (!DecodeAndShow(jpeg_data.data(), jpeg_len)) {
        std::cerr << "JPEG cozme hatasi!\n";
        ShowErrorOnTFT("DECODE FAIL");
        myTFT.TFTPowerDown();
        return 1;
    }

    std::cout << "Islem tamamlandi. Goruntu 5 saniye ekranda kalacak.\n";
    sleep(5);

    myTFT.TFTPowerDown();
    return 0;
}

//================== Donanım Fonksiyonları ====================

static uint8_t SetupDisplay()
{
    std::cout << "TFT Baslatiliyor...\n";
    myTFT.TFTSetupGPIO(RST_TFT, DC_TFT);
    myTFT.TFTInitScreenSize(OFFSET_COL, OFFSET_ROW, TFT_WIDTH, TFT_HEIGHT);

    if (myTFT.TFTInitPCBType(myTFT.TFT_ST7735R_Red, SPI_DEV, SPI_CHANNEL, SPI_SPEED, SPI_FLAGS, GPIO_CHIP_DEV) != rdlib::Success) {
        return 1;
    }

    delayMilliSecRDL(50);
    myTFT.TFTsetRotation(myTFT.Degrees_0);
    myTFT.fillScreen(myTFT.RDLC_BLACK);
    myTFT.setFont(font_pico);
    return 0;
}

static bool CaptureJPEG(std::vector<uint8_t>& jpeg_buf, uint32_t& jpeg_len)
{
    // SPI ve I2C açılışı
    int spi_cam = spi_open("/dev/spidev0.0", 8000000);
    if (spi_cam < 0) return false;

    struct arduchip cam;
    arduchip_init(&cam, spi_cam);

    int i2c_cam = i2c_open("/dev/i2c-1", OV2640_I2C_ADDR);
    if (i2c_cam < 0) { spi_close(spi_cam); return false; }

    // Kamera Ayarları
    ov2640_init(i2c_cam);
    ov2640_set_qqvga_jpeg(i2c_cam);
    sleep(1); // Sensörün ışığa alışması için bekleme

    // --- KRİTİK: DOUBLE CAPTURE MANTIĞI (Gecikmeyi önler) ---
    // 1. Sahte yakalama ile tamponu boşalt
    arduchip_start_capture(&cam);
    arduchip_wait_capture_done(&cam, 1000);
    arduchip_write_reg(&cam, ARDUCHIP_FIFO, FIFO_CLEAR_MASK);

    // 2. Donanım işaretçilerini sıfırla
    arduchip_write_reg(&cam, ARDUCHIP_FIFO, FIFO_RDPTR_RST_MASK);
    arduchip_write_reg(&cam, ARDUCHIP_FIFO, FIFO_WRPTR_RST_MASK);
    usleep(50000);

    // 3. Gerçek (Taze) yakalamayı başlat
    arduchip_start_capture(&cam);
    if (arduchip_wait_capture_done(&cam, 2000) < 0) {
        i2c_close(i2c_cam); spi_close(spi_cam); return false;
    }

    // Veri uzunluğunu al ve belleği hazırla
    jpeg_len = arduchip_read_fifo_length(&cam);
    if (jpeg_len == 0 || jpeg_len > 400 * 1024) {
        i2c_close(i2c_cam); spi_close(spi_cam); return false;
    }

    jpeg_buf.resize(jpeg_len);
    arduchip_read_fifo_burst(&cam, jpeg_buf.data(), jpeg_len);

    i2c_close(i2c_cam);
    spi_close(spi_cam);
    return true;
}

static bool DecodeAndShow(const uint8_t* jpeg_data, uint32_t jpeg_len)
{
    uint16_t* rgb565 = nullptr;
    int img_w = 0, img_h = 0;

    // JPEG -> RGB565 Çevrimi
    if (jpeg_to_rgb565(jpeg_data, jpeg_len, &rgb565, &img_w, &img_h) != 0 || !rgb565) {
        return false;
    }

    // Ekran ortalaması (Crop)
    int x0 = (img_w - TFT_WIDTH) / 2;
    int y0 = (img_h - TFT_HEIGHT) / 2;

    // Ekrana Piksel Piksel Yazma
    for (int y = 0; y < TFT_HEIGHT; ++y) {
        for (int x = 0; x < TFT_WIDTH; ++x) {
            // Kaynak resimden ilgili pikseli al
            uint16_t color = rgb565[(y0 + y) * img_w + (x0 + x)];
            
            // Not: Renkler tersse aşağıdaki satırı aktif et:
            // color = (color >> 8) | (color << 8);

            myTFT.drawPixel(x, y, color);
        }
    }

    free(rgb565);
    return true;
}

static void ShowErrorOnTFT(const char* msg)
{
    myTFT.fillScreen(myTFT.RDLC_BLACK);
    myTFT.setTextColor(myTFT.RDLC_RED, myTFT.RDLC_BLACK);
    myTFT.setCursor(5, 5);
    myTFT.println(msg);
}

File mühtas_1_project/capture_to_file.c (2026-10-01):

#include <stdio.h>
#include <stdlib.h>
#include <stdint.h>
#include <unistd.h>
#include <string.h>

#include "spi_linux.h"
#include "i2c_linux.h"
#include "arduchip.h"
#include "ov2640.h"

#define MAX_JPEG_SIZE (400 * 1024)

int main(void)
{
    int spi_cam = spi_open("/dev/spidev0.0", 8000000);
    if (spi_cam < 0) return 1;

    struct arduchip cam;
    arduchip_init(&cam, spi_cam);

    int i2c_cam = i2c_open("/dev/i2c-1", OV2640_I2C_ADDR);
    if (i2c_cam < 0) { spi_close(spi_cam); return 1; }

    // 1) ArduChip SPI Test
    arduchip_write_reg(&cam, ARDUCHIP_TEST1, 0x55);
    if (arduchip_read_reg(&cam, ARDUCHIP_TEST1) != 0x55) {
        fprintf(stderr, "SPI Test Hatasi!\n");
        return 1;
    }

    // 2) Sensör Başlatma
    ov2640_init(i2c_cam);
    ov2640_set_qqvga_jpeg(i2c_cam);
    sleep(1); 

    // --- KRİTİK NOKTA: DUMMY CAPTURE (Gecikmeyi siler) ---
    // Önce içeride kalmış olabilecek eski kareyi tetikleyip bitiriyoruz
    arduchip_start_capture(&cam);
    arduchip_wait_capture_done(&cam, 1000);
    arduchip_write_reg(&cam, ARDUCHIP_FIFO, 0x01); // Temizle
    usleep(50000); // 50ms bekle

    // --- ASIL CAPTURE ---
    // Şimdi tertemiz bir başlangıç yapıyoruz
    arduchip_write_reg(&cam, ARDUCHIP_FIFO, 0x10); // Read Pointer Reset
    arduchip_write_reg(&cam, ARDUCHIP_FIFO, 0x20); // Write Pointer Reset
    
    printf("Gercek zamanli goruntu yakalaniyor...\n");
    arduchip_start_capture(&cam);

    if (arduchip_wait_capture_done(&cam, 2000) < 0) {
        fprintf(stderr, "Yakalama zaman asimi!\n");
        return 1;
    }

    // 3) Boyutu Oku ve Hafıza Ayır
    uint32_t jpeg_len = arduchip_read_fifo_length(&cam);
    if (jpeg_len == 0 || jpeg_len > MAX_JPEG_SIZE) {
        fprintf(stderr, "Hatali boyut: %u\n", jpeg_len);
        return 1;
    }

    uint8_t *jpeg_buf = (uint8_t *)malloc(jpeg_len);
    if (!jpeg_buf) return 1;

    // 4) FIFO Verisini Çek
    arduchip_read_fifo_burst(&cam, jpeg_buf, jpeg_len);

    // 5) Dosyaya Kaydet
    FILE *fj = fopen("frame.jpg", "wb");
    if (fj) {
        fwrite(jpeg_buf, 1, jpeg_len, fj);
        fclose(fj);
        printf("Guncel goruntu frame.jpg olarak kaydedildi. Boyut: %u byte\n", jpeg_len);
    }

    // Temizlik
    free(jpeg_buf);
    i2c_close(i2c_cam);
    spi_close(spi_cam);

    return 0;
}
